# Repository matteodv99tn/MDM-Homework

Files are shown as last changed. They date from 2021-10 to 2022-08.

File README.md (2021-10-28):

# MDM-Homework
## LaTeX crash course

Le cose che vi spiego qua le scrivo abbastanza velocemente, la cosa più comoda è comunque provare e sperimentare, e in caso vedere anche la parte di documento già scritta.

Il testo si scrive normalmente nell'editor, ma per scrivere in modalità matematica nel testo bisogna mettere le funzioni matematiche nel simbolo del dollaro del tipo `$ f_l(x) = 10 $`; in modalità matematica con `_` si può indicare il pedice, con `^` l'apice.
Per andare a capo riga all'interno di uno stesso paragrafo non bisogna andare a capo riga nel domumento .tex ma basta mettere due barrette `\\` così. Per creare invece un nuovo paragrafo (ossia andare a capo riga e aggiungere un rientro alla prima riga) è necessario lasciare nell'editor di testo almeno una riga vuota.

Per scrivere le equazioni centrate in una nuva riga è possibile sfruttare due metodi: se l'equazione non deve essere numerata allora bisogna creare un nuovo ambiente 

`\begin{equation}`

      la mia equazione

 `\end{equation}`
 
 Se non si vuole avere il numero progressivo a destra basta inserire l'equazione in questo modo `\[ equazione \]`.

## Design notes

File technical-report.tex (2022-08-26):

\documentclass[11pt,a4paper]{article}
\usepackage[utf8]{inputenc}
\usepackage[T1]{fontenc}
\usepackage{amsmath}
\usepackage{amsfonts}
\usepackage{amssymb}
\usepackage{graphicx}
\usepackage{multicol}
\usepackage{etoolbox}
\usepackage[dvipsnames]{xcolor}
\usepackage[width=15.00cm, height=23.00cm]{geometry}
\usepackage[margin=1cm]{caption}
\usepackage[sorting=none]{biblatex} 
\usepackage{hyperref}
\usepackage{enumerate}
\usepackage{textcomp}
\usepackage{subcaption}
\usepackage{sidecap}
\usepackage{rotating}
\usepackage{subcaption}
\usepackage{pdfpages}

\addbibresource{bibliography.bib} 
\graphicspath{{Images/}}
\captionsetup{font = {it, small}, labelfont={color=NavyBlue, bf}}

%% Fonts
\usepackage[osf,sc]{mathpazo}
\usepackage[scaled=0.90]{helvet}
\usepackage[scaled=0.85]{beramono}

\begin{document}
	
	\pagenumbering{roman}
	\thispagestyle{empty}
	\begin{center}
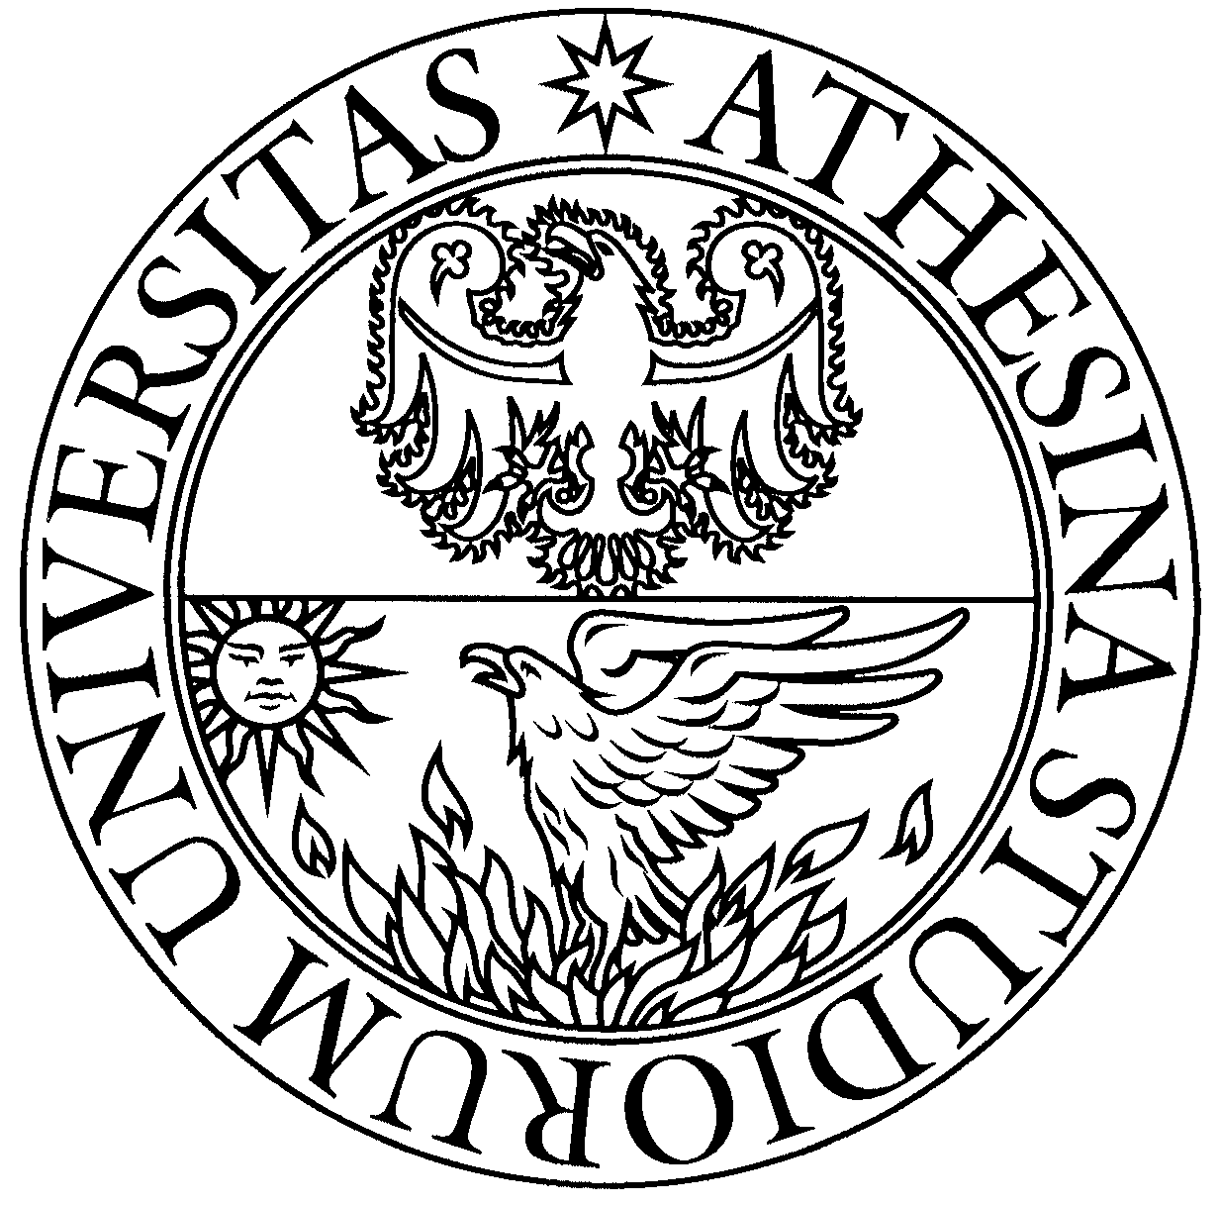
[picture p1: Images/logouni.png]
		
		\vspace{2cm}
		
		{\Large Group project for the course of \\ \vspace{3mm}
		\textbf{Mechanical Design for Mechatronics} \\ \vspace{1cm}
		Prof.: Rustighi Emiliano} \vspace{1cm}
	
		\rule{5cm}{0.5pt} \\ \vspace{1cm}
		{\Large Technical report} \\ \vspace{3mm}
		{\LARGE \textbf{Design of the Structure of an Automated Machine \\ for Agricultural Purposes}} \\ \vspace{1cm}
		
		\rule{5cm}{0.5pt} \vspace{1cm}
		
		\begin{multicols}{2}
			Bontempelli Elia \\
			Rizzardi Alessandro \\
			Dalle Vedove Matteo \\
			Zambotti Beatrice
		\end{multicols}
		\vspace{1cm}
		
		\today
		
	\end{center}
	
	\newpage
	\tableofcontents
	
	\newpage
	
	\pagenumbering{arabic}
	\setcounter{page}{1}
	
	% Importare qua le varie sezioni
	\input{Parts/designspecification}
	\input{Parts/preliminarydesign}
	\input{Parts/design}
	\input{Parts/developement}
	\input{Parts/conclusions}

	\appendix	
	\counterwithin{figure}{section}
	\counterwithin{table}{section}

	% Inserire da qua le appendici
	\clearpage
	\section{Appendix}
	\counterwithin{table}{subsection}
	\input{Appendix/material.tex}
	\input{Appendix/BOM.tex}
	\input{Appendix/drawings.tex}
	
	\clearpage
	\section{Bibliography and references}
	In order of first appearance:
	\printbibliography[heading=none]
	
	\newpage
	%\input{LatexCrashCourse}
	
\end{document}

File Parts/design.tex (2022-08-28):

\section{Preliminary design}
	Based on the selected concept the simplest body diagram has been created in order to start the dimensioning of the main elements of the structure. Considering the possible practical implementation of the system, the symbolic representation of the moving frame has been made (figure \ref{fig:freebodydiagramframe}).
	
	\begin{figure}[bht]
		\centering 
		\caption{schematic representation of the moving frame supporting the arm; blue arrows are describes the rotational degree of freedom left by the joints.}
		\label{fig:freebodydiagramframe}
	\end{figure}
	
	The design involves a main elevated track (body 2) supported by two vertical supporting beams (bodies 1 and 3); the connection between body 1 and 2 is constituted by a full joint in point $B$ constraining all 6 degrees of freedom while the connection of the track with the other support is done by a hinge that leaves free the rotation over the global $x$ axis. The two vertical supports can slide on two parallel tracks and the associated prismatic joints constraints respectively 5 and 4 degrees of freedom in $A$ and $D$, leaving the system free to slide along the $x$ global axis; the choice of leaving also $D$ in as free to rotate aims at reducing redundant constraints, reducing hyperstatic variables with a design that accommodates misalignments in the position of the two parallel tracks placed at ground.

	\begin{figure}[p]
		\begin{subfigure}{\linewidth}			
			\centering  \caption{}
		\end{subfigure}
		\begin{subfigure}{\linewidth}			
			\centering  \caption{}
		\end{subfigure}
		\caption{free body diagram (a) and reference frames (b) used for the description of the internal loads of the beam. In (a) the structure has been disassembled at the pivot point $C$ in order to describe the reaction forces transmitted.}
		\label{fig:fbd-frames}
	\end{figure}
	As simplification on both the geometry and the load we consider:
	\begin{itemize}
		\item on the elevated track the loads transferred by the working appendix are modelled as a pure vertical force $F$ (mainly related to the approximate weight of the turret that contains all equipment) and a torque $T$ that model's the one due to the plower; the eccentricities of both forces are in this case neglected and the application of application of both actions is placed at a distance $\zeta$ referred to the local coordinate $z$ of the elevated track, figure \ref{fig:fbd-frames}\textit{\textit{(b)}};
		
		\item the vertical supports are equally dimensioned and present a characteristic height $H = 700mm$; the elevated track connecting them has length $L = 3000mm$ as dictated by the customer requirements;
		
		\item figure \ref{fig:fbd-frames}\textit{(a)} shows the free body diagram of the structure and thus the set of external actions and reactions applied; figure \ref{fig:fbd-frames}\textit{(b)} reports instead the reference frames with respective origin with respect to which internal loads are calculated.
		
		The full joint in $B$ has not been described (as the connection preserves the continuity of the actions transmitted by the body), however the final design will imply the connection of two separate beams by means of a gusset.	
		
	\end{itemize}
	
	After having written the Newton-Euler equations of the two bodies making the whole structure, we observe that only 11 out of 14 reactions forces are independent; chosen the hyperstatic variables $X_1 = M_{Az},X_2 = M_{Dy}, X_3 = M_{Ax}$ to reduce the problem to an isostatic one, the parametric definitions of the reaction forces is
	\[ R_{Az} = \frac{F (L-\zeta) - X_3}{L} \qquad R_{Cz} = R_{Dz} =\frac{F\zeta + X_3}{L} \] \[ M_{Ay} = M_{Cy} = X_2 \qquad M_{Cz} = M_{Dz} = T-X_1 \]
	Non mentioned actions are identically zero. To solve the hyper-static problem the Castigliano's theorem has been used, computing the elastic energy $U_e$ of the structure neglecting shear loads:
	\[ U_e = \sum_{i=1}^3 \int_0 ^{l_i}  \left( \frac{N_i^2}{2EA_i} + \frac{M_{x,i}^2}{2 EI_{xx,i}} + \frac{M_{y,i}^2}{2 E I_{yy,i}} + \frac{M_{z,i}^2}{2G J_{t,i}}  \right)\, dz \]
	Assuming the generalized displacement related to the hyper-static variables is zero, solving the equations $\partial U_e / \partial X_i = 0$, the solution that we achieve is still depending on the geometrical parameters of the sections that are still unknown. To simplify the calculations we assumed $A_1 = 0$, giving the result
	\[ X_1 = T \qquad X_2 = 0 \qquad X_3 = F \frac{L-2\zeta}{2} \]

	In this preliminary design phase in order to over-estimate the loads the the frame should bear a force $F = 200 N$ is considered (modelling the weight of about $20kg$, related to all the carried equipment on the moving arm including batteries and filled water tank) and the nominal value of the torque $T = 0.8 N\cdot m$ as in the requirements specification.
	
	\paragraph{Choice of the standard beams} With the preliminary design model described, different solutions can be found looking from various vendors present in the marker. In particular for the project main reference has been made to the Parker IPS catalogue \cite{parker-ds} due to the high availability of accessories components, however similar product can be found by other vendors (as group we also evaluated 8020 \cite{8020-ds} and Tslots by Bonnel Aluminum \cite{tslot-ds}).
	
	Data-sheets presents information about the section area $A$ and second moments of area $I_{xx},I_{yy}$ respect the primary axes, however no information is given for the torsional rigidity $J_t$ and so the related component is in the calculation neglected. 
	
	\input{Table/beamchoice.tex}
	
	After an iterative process, table \ref{tab:beamchoice} shows the sections drawing and associated geometric properties of the chosen components for both elevated track and supporting beams. This choice determines a safety factor $\phi = 3.8$ for the whole structure that's a safe value for us; it is true that we neglected both shear and torque loads, and in practical applications other external and unexpected actions might act on the frame, however it is also true that the geometric simplification $A_1 = 0$ in the solution of the hyperstatic problem heavily reduced the ability of the system to bear load (as we will see in the final static verification).
	
	As a side note, our design was forced to use the $40mm$ T-slot series (even if a $30mm$ profile would have let us achieve similar results with lower weights and costs) as it's the only one that disposes off-the-shelf linear roller system that can be easily mounted and used (choosing other profile series would have ended in custom solution that's undesired by the product design specifications).

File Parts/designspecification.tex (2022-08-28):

\section{Product design specification}
	The goal of our project is to create our implementation of the \textit{CyberOrto} \cite{cyberorto} made by \textit{Mindshub}, a non-lucrative association based in Ala (Trentino). The goal of this robot is to automatically handle an amateur vegetable garden by performing this 3 principle actions:
	\begin{enumerate}[i)]
		\item planting the seeds  of the desired plant in a location decided by the user using a web interface;
		\item constantly provide water to the vegetable;
		\item extirpate undesired plants.
	\end{enumerate}

	By talking with the association that worked (and is still improving) on the product we acknowledged the following requirements (mainly related to the functionality of the product) that the machine has to satisfy:
	\begin{enumerate}[i)]
		\item the arm appendix must suits an interface that allows to have an interchangeable set of tools (like the one used to plow the terrain or plant the seeds);
		
		\item the arm appendix should accommodate a small pipe in order to irrigate the vegetables; in particular this has to be connected to an external reservoir (with arbitrary dimension) or by using an internal reservoir on the moving structure of at least $4l$ (that can periodically be refilled by means of a resting station) if it's not possible to directly attach the arm to the main reservoir;
		
		\item the minimum accepted working area of the robot is a rectangle of dimension $4m\times 3m$; the robot should be design keeping in mind the possibility to increase the working area by expanding it over one edge (for example having the possibility to work on a $8m\times 3m$ terrain);
		
		\item the structure can house the electronic control unit of the robot that's remotely connected to the server using wireless connection and by doing so should accommodate a battery the allows the robot to work for at least $4h$. The power consumption of the structure should be minimized if possible (at the actual state the prototype consumes $40W$ and has a battery of $240 Wh$ weighting $6.3kg$);
		
		\item regarding the accuracy of the movement of the system the allowed backlash on the working point should always be less then $1cm$ with the control technique implemented and the goal is to have maximum $5mm$ of deviation from the nominal value;
		
		\item the structure should be mainly composed of standard components and should be as cheap as possible in order to make it affordable for everyone.
	\end{enumerate}

	\paragraph{Loads and operating conditions} The structure should be able to perform all it's operation while being safe and fully functional. For the design and the verification of the structure the loads related to wind can be neglected due to the presence of an anemometer that's mounted on the robot that's ensuring that the robot works only on a sufficiently safe environment.
	
	The heavier operation performed by the robot is the extirpation that's done by plowing the soil with a rotating disk attached to a motor that uses three nails to move the terrain in the nearby of the target zone. In the current state the mounted motor that performs this operation exerts a torque $T_\textrm{plower} = 0.8 N\cdot m$, value that will be used for the dimensioning and verification phases.

	\subsection{Requirements \& specifications}
		With this premise being said, it's possible to express the main requirements, associated to the aim dictated by our customer and our design rules, and the specifications of the designed machine. All this information, collected in table \ref{tab:requirementsspecifications}, must be considered in each step of the design phase in order to develop the mechanical solution.
		
		\input{Tables/requirements-specifications.tex}
		
		While developing the project other factors should be kept in mind such:
		\begin{itemize}
			\item the possibility to pack all the necessary components in a \textit{small} transportation box (the box shouldn't present and edge greater than $2m$, maximum sum of all the edges less then $3m$) in order to avoid shipping issues;
			
			\item the kit should be feasible to all private enthusiast that enjoy \textit{do-it-yourself} projects and this has to kept in mind; the final assembly should be made possible by common mounting tools (such screwdrivers, Allen keys...) that can be easily purchased and used by the customer; for the same reason welding finishes are not recommended.
		\end{itemize}
	
	\subsection{Goal of our project}
		Designing the whole machine is out of our scopes as it is very complex and requires knowledge that we still miss, so we decided to focus our work in the design of the main structure of the robot putting effort in the structural verification as the goal of the course.

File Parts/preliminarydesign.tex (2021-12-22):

\section{Concept generation}
	With all the premise that lead the development of the project, the first thing that has to be done is generate the concept that can later be compared to choose the best design solution that can become a concrete realization of the ideas.
	
	\paragraph{Kinematic configurations} The first key operation that the robot has to perform is reaching a desired point on the working space and so, in planar kinematics, the machine should present two degrees of freedom that allow to reach all the possible positions; this can be done considering 3 main joint configuration that allows to perform such operations:
	\begin{itemize}
		\item double prismatic joints (figure \ref{fig:kinematiccoupling}.a) where two perpendicular linear guides can be used to move on the plane;
		\item prismatic and revolute joint (figure \ref{fig:kinematiccoupling}.b) where the arm that's free to rotate it's mounted on top of a linear guide. This kind of kinematic chain is currently used by the MindsHub concept;
		\item double revolute joints (figure \ref{fig:kinematiccoupling}.c), typical configuration of a robot arm, that constraint the framing point to be fixed.
	\end{itemize}
	
	\begin{figure}[bht]
	\centering
		\begin{subfigure}{0.32\linewidth}
			\centering 
			\caption{}
		\end{subfigure}
		\begin{subfigure}{0.32\linewidth}
			\centering 
			\caption{}
		\end{subfigure}
		\begin{subfigure}{0.32\linewidth}
			\centering 
			\caption{}
		\end{subfigure}
		\caption{main kinematics coupling that allows to univocally determine the position of a point $A$ in a plane: (a) double prismatic joints, (b) prismatic and revolute joint, (c) double revolute joints.}
		\label{fig:kinematiccoupling}
	\end{figure}
	
	By a first analysis the third configuration (double revolute joint) isn't feasible for the project due to the fact that the system presents a fixed pivot point respect to the frame and to work more area it's mandatory to increase the length of the edges (and this is an issue for the \textit{extendibility} of the machine).
	
	\paragraph{Concept \#1} The first concept (figure \ref{fig:prot:1}) is realised with a double prismatic joint. In particular point $A$ and $A'$ lies on parallel tracks placed on the ground that can be extended in order to increase the cultivated area. The working arm can move along an elevated beam connecting the track (point $B$) and can move vertically to cultivate point $P$.
	
	\begin{figure}[bht]
		\centering 
		\caption{concept \#1 realised with double prismatic joint.}
		\label{fig:prot:1}
	\end{figure}
	
	This structure present a frame for the arm that's stable while operating due to it's arch structure; possible problem to this implementation is that long elevated beam (subjected to the loads of the arms and it's mass) can deflect and fail statically. Also, if possible, rotoidal coupling should be used (and for this we can refer to concept \#2).
	
	\paragraph{Concept \#2}	The second concept (figure \ref{fig:prot:2}) is similar to the first one but one prismatic joint is replaced with a revolute connection put in the middle of the elevated beam. The length of the edge $BP$ from a top view must be equal to half the length of the supporting bar in order to reach all points in the rectangular space.

	\begin{figure}[bht]
		\centering 
		\caption{concept \#2 realised with a combination of both prismatic and revolute joint.}
		\label{fig:prot:2}
	\end{figure}
	
	This structure also presents the pro of concept \#1 of having a stable frame structure for the operating arm due to it's arch conformation and, as addition, uses a revolute joint to control the second degree of freedom of the arm. However this implementation increases the mechanical load on the elevated beam (increasing the torsion due to the higher arm of the actions on the tool tip respect to the elevated bar).
	
	\paragraph{Concept \#3}	The third concept (figure \ref{fig:prot:3}) is similar to \#2 but instead of using two parallel tracks, the prismatic joint uses only one of them.

	\begin{SCfigure}[1.5][bht]
		\centering 
		\caption{concept \#3  realised with a combination of both prismatic and revolute joint.}
		\label{fig:prot:3}
	\end{SCfigure}

	This implementation avoid the problem of high deflection of concepts \#1 and \#2 by removing the long elevated framing beam, but also increases the reactional momentum that the prismatic joint $A$ should bear in order to maintain stable the system.

\subsection{Decision matrix}
	With a brief overview of the 3 main concept generated, the unbiased choice can be performed by constructing and evaluating the decision matrix (table \ref{tab:decitionmatrix}). The main objective evaluated are:
	
	\input{Table/decisionmatrix.tex}
	
	\begin{itemize}
		\item costs: based on the estimated material cost considering quantity and types of parts that can be used for the implementation;
		\item reliability: expected mechanical  resistance of the structure subjected to nominal loads as well as unexpected external loads (such environment of customer that interact with the structure);
		
		\item lifetime: expected lifetime of the product based on fatigue considerations;
		
		\item adaptability: criteria that evaluates how easy is to modify geometrical parameters to meet specific custom requirement of the final customer based on asperity and tolerances of the terrain to cultivate;
		
		\item team experience: based on the overall design feasibility made by the team.
	\end{itemize}

	With the decision matrix completed the chosen concept is the first on which the motion is performed only by prismatic joints.

\input{Parts/materialselection}

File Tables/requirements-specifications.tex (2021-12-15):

\begin{table}[pbt]
	\rule{\linewidth}{2pt}
	\caption{full list of requirements and specifications for the CyberOrto project.}
	\label{tab:requirementsspecifications}
	\rule{\linewidth}{1pt} \vspace{0mm}	
	
	\centering
	\begin{tabular}{p{0.2cm} p{8cm} p{5cm} }
		\multicolumn{2}{l}{ \textbf{1) Geometry:} } \\
		& 1.1) dimension of the terrain to cultive & at least $4m\times 3m$, extendible if possible \\
		& 1.2) vertical clearance from the ground of the robot while moving & $\geq 50cm$ \\
		
		\multicolumn{2}{l}{ \textbf{2) Kinematic:} } \\
		& 2.1) time travel between further points in the field & $ \leq 10s$ \\	
		& 2.2) accuracy of the working appendix respect to nominal value & max $\pm 1cm$, target $\pm 5mm$ \\		
		
		\multicolumn{2}{l}{ \textbf{3) Energy:} } \\
		& 3.1) low energy consumption & max $40W$, target $20W$ \\
		& 3.2) in-device battery with docking station & battery $\geq 240 Wh$ or $4+$ hour of work\\
				
		\multicolumn{2}{l}{ \textbf{4) Functionalities:} } \\
		& 4.1a) provide direct water access to irrigate the soil \\
		& 4.1b) or provide a reservoir that can be automatically refilled on a docking station & $\geq 4l$ \\
		& 4.2) standard mount on the appendix arm that can fit multiple working tools \\
		& 4.3) plowing the terrain & $T_\textrm{plower,max} = 0.8 N\cdot m $\\
		& 4.4) provide a pneumatic circuit used for the appendix that plants seeds \\
		
		\multicolumn{2}{l}{ \textbf{5) Materials:} } \\
		& 5.1) components standardization & very high \\
		& 5.2) materials should be weather proof (oxidation free) \\
		
		\multicolumn{2}{l}{ \textbf{6) Terms of use:} } \\
		& 6.1) easy to assemble & max 2 persons required \\
		& 6.2) fatigue resistance & infinite life-cycles if possible, min $10^6$ \\
		& 6.3) insensible to environmental conditions (weather and dirt)\\

		\multicolumn{2}{l}{ \textbf{7) Loading conditions:} } \\
		&  7.1) wind and environmental actions can be neglected with robot in action\\
		
		\multicolumn{2}{l}{ \textbf{8) Costs:} } & $\leq \textrm{\texteuro}2\,000$ \\
	\end{tabular}
	
	\vspace{3mm}
	
	\rule{\linewidth}{2pt}

\end{table}

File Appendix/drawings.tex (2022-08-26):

\clearpage
\section{Technical drawings}
\subsection{Gear and rack design} \label{draw:gearrack}
In the following page the detailed representation of the custom created rack and gear design is reported.

\includepdf[fitpaper=true]{Drawings/rack.pdf}
\includepdf[fitpaper=true]{Drawings/gear.pdf}

\subsection{Final CAD}

\includepdf[fitpaper=true]{Drawings/Overview.pdf}

\subsection{Connection assembly details}
In the following pages it's possible to find instructions on how to assembly the rack on top of the T-slot profiles and how to assemble the main junctions of the frame, namely connections $A$, $B$, $C$ and $D$.

\includepdf[fitpaper=true]{Drawings/Mounting.pdf}
\includepdf[fitpaper=true]{Drawings/Connessione-A.pdf}
\includepdf[fitpaper=true]{Drawings/Connessione-B.pdf}
\includepdf[fitpaper=true]{Drawings/Connessione-C.pdf}
\includepdf[fitpaper=true]{Drawings/Connessione-D.pdf}

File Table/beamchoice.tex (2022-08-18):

\begin{table}[bt]
	\rule{\linewidth}{2pt}
	\caption{selected beams section chosen from the Parker IPS catalogue \cite{parker-ds} and related main properties (area, moments of inertia and weight per unit length).}
	\label{tab:beamchoice}
	\rule{\linewidth}{1pt} \vspace{0mm}	
	
	\begin{center}
		\begin{tabular}{p{3cm} | c c c c  |  l }
			& Area & \multicolumn{2}{c}{Moments of inertia} & Weight \\
			Usage & $A [cm^2]$ & $I_{xx} [cm^4]$ & $I_{yy} [cm^4]$ & $\rho [kg/m]$ & Product code \\ \hline
			track & 6.65 & 9.46 & 9.46 & 1.72 & \texttt{10-040} \\
			supports & 5.20 & 8.27 & 8.27 & 1.41 & \texttt{10-540} \\
		\end{tabular}
	\end{center}
	
	\vspace{3mm}
	\rule{\linewidth}{1pt}
	{\scriptsize
		\begin{multicols}{2}
		\begin{center}
				\\		
			
		\end{center}
		\end{multicols}
		Sections for the track beam (on the left) and the supports (right).
	}	
	
	\rule{\linewidth}{2pt}
	
\end{table}

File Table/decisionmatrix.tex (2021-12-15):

\begin{sidewaystable}[p]
	\rule{\linewidth}{2pt}
	\caption{decision matrix.}
	\label{tab:decitionmatrix}
	\rule{\linewidth}{1pt} \vspace{0mm}	
	
	\begin{center}
		\begin{tabular}{p{3cm} c c | c c c | c c c | c c c}
			\multicolumn{3}{c}{} & \multicolumn{3}{c}{Concept \#1} & \multicolumn{3}{c}{Concept \#2} & \multicolumn{3}{c}{Concept \#3} \\
			Objective &  Weight & Parameter &
			Mag & Score & Value &
			Mag & Score & Value &
			Mag & Score & Value \\ \hline
			Material costs & 0.2 & relative \texteuro &
			medium & 7 & 1.4 &
			high & 5 & 1 & 
			low & 9 & 1.8 \\
			
			Reliability & 0.3 & experience &
			good & 8 & 2.4 &
			okay & 6 & 1.8 & 
			poor-fair & 3 & 0.9 \\
			
			Lifetime & 0.15 & experience &
			great & 10 & 1.5 &
			good & 8 & 1.2 & 
			fair & 4 & 0.6 \\
			
			Adaptability & 0.2 & experience &
			good & 8 & 1.6 &
			okay-good & 7 & 1.4 & 
			fair & 4 & 0.8 \\
			
			Team experience & 0.15 & experience &
			good & 8 & 1.2 &
			great & 10 & 1.5 & 
			fair & 4 & 0.6 \\			
			
			\hline
			\multicolumn{3}{r|}{Overall score:} &&& \textbf{8.1} &&& 6.9 &&& 4.7
		\end{tabular}
	\end{center}
	
	\vspace{3mm}
	\rule{\linewidth}{1pt}
	{
		\scriptsize
		Qualitative score assignments:  poor = 2, fair = 4, okay = 6, good = 8, great = 10.
	}	
	
	\rule{\linewidth}{2pt}
	
\end{sidewaystable}

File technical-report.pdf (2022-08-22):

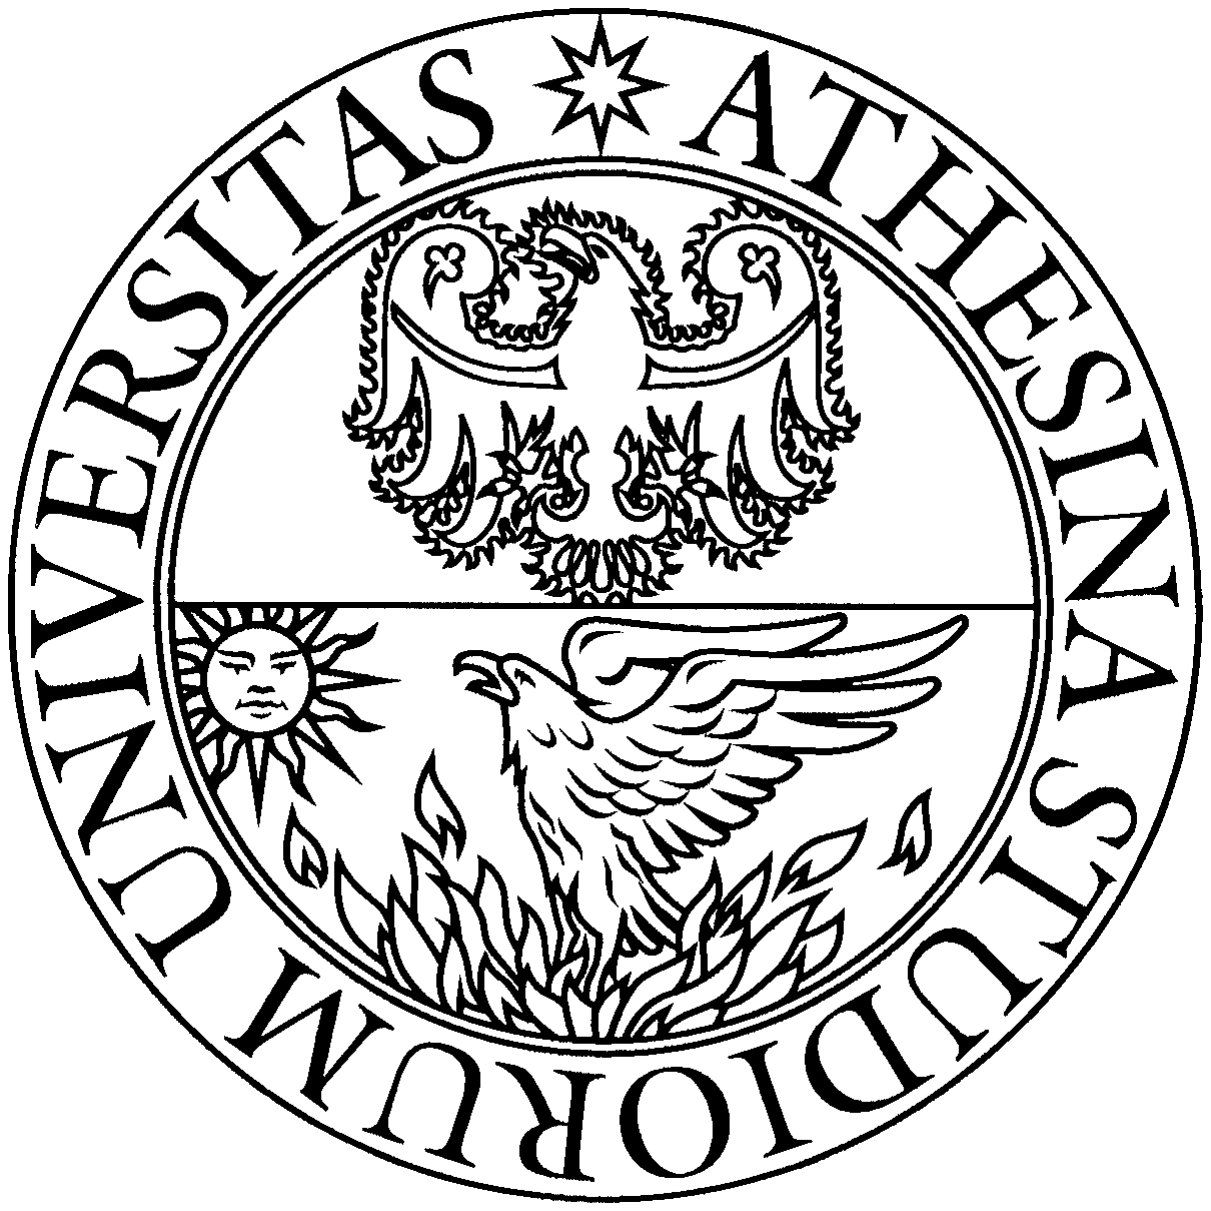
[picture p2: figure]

## Group project for the course of

### Mechanical Design for Mechatronics

## Prof.: Rustighi Emiliano

## Technical report

## Design of the Structure of an Automated Machine for Agricultural Purposes

Bontempelli Elia
Rizzardi Alessandro

Dalle Vedove Matteo
Zambotti Beatrice

August 22, 2022

### Contents

1 Product design specification | 1
2 Concept generation | 2
3 Preliminary design | 8
4 Design process and verifications | 11
A Appendix | 22
B Bibliography and references | 26

ii

### 1 Product design specification

The goal of our project is to create our implementation of the CyberOrto [1] made by Mindshub, a non-lucrative association based in Ala (Trentino). The goal of this robot is to automatically handle an amateur vegetable garden by performing this 3 principle actions:

i) planting the seeds of the desired plant in a location decided by the user using a web interface;

ii) constantly provide water to the vegetable;

iii) extirpate undesired plants.

By talking with the association that worked (and is still improving) on the product we acknowledged the following requirements (mainly related to the functionality of the product) that the machine has to satisfy:

i) the arm appendix must suits an interface that allows to have an interchangeable set of tools (like the one use to plow the terrain);

ii) the arm appendix should accommodate a small pipe in order to irrigate the vegetables; in particular this has to be connected to an external reservoir (with no dimension specified if it’s position is fixed) or by using an internal reservoir on the moving structure of at least 4l (that can periodically be refilled) if it’s not possible to directly attach the arm to the main reservoir;

iii) the minimum accepted working area of the robot is a rectangle of dimension 4m × 3m; the robot should be design keeping in mind the possibility to increase the working area by expanding it over one edge (for example having the possibility to work on a 8m × 3m terrain);

iv) the structure can house the electronic control unit of the robot that’s remotely connected to the server using wireless connection and by doing so should accommodate a battery the allows the robot to work for at least 4h. The power consumption of the structure should be minimized if possible (at the actual state the prototype consumes 40W and has a battery of 240Wh weighting 6.3kg);

v) regarding the accuracy of the movement of the system the allowed backlash on the working point should always be less then 1cm with the control technique implemented and the goal is to have maximum 5mm of deviation from the nominal value;

vi) the structure should be mainly composed of standard components and should be as cheap as possible in order to make it affordable for everyone.

Loads and operating conditions The structure should be able to perform all it’s operation while being safe and fully functional. For the design and the verification of the structure the loads related to wind can be neglected due to the presence of an anemometer that’s mounted on the robot that’s ensuring that the robot works only on a sufficiently safe environment.

1

The heavier operation performed by the robot is the extirpation that’s done by plowing the soil with a rotating element AGGIUNGERE UNA BREVE DESCRIZIONE. Considering the actual mounted motor to perform this operation the torque that has to be transmitted to the plower is of Tplower = 0.8N · m.

### 1.1 Requirements & specifications

With this promise being said, it’s possible to express the main requirements, associated to the aim dictated by our customer and our design rules, and the specifications of the designed machine. All this information, collected in table 1, has to be considered in each step of the design phase in order to develop the mechanical solution.
While developing the project other factors should be kept in mind:
- the possibility to pack all the necessary components in a small transportation box (the box shouldn’t present and edge greater than 2m, maximum sum of all the edges less then 3m) in order to avoid shipping issues;
- the kit should be feasible to all private enthusiast that enjoy do-it-yourself projects and this has to kept in mind; the final assembly should be made possible by common mounting tools (such screwdrivers, Allen keys...) that can be easily purchased and used by the customer; for the same reason welding finishes are not recommended.

### 1.2 Goal of our project

Designing the whole machine is out of our scopes as it is very complex and requires knowledge that we still miss, so we decided to focus our work in the design of the main structure of the robot putting effort in the structural verification as the goal of the course.

### 2 Concept generation

With all the premise that lead the development of the project, the first thing that has to be done is generate the concept that can later be compared to choose the best design solution that can become a concrete realization of the ideas.

Kinematic configurations The first key operation that the robot has to perform is reaching a desired point on the working space and so, in planar kinematics, the machine should present two degrees of freedom that allow to reach all the possible positions; this can be done considering 3 main joint configuration that allows to perform such operations:

- double prismatic joints (figure 1.a) where two perpendicular linear guides can be used to move on the plane;
- prismatic and revolute joint (figure 1.b) where the arm that’s free to rotate it’s mounted on top of a linear guide. This kind of kinematic chain is currently used by the MindsHub concept;

2

Table 1: full list of requirements and specifications for the CyberOrto project.

1) Geometry:
1.1) dimension of the terrain to cultive | at least 4m × 3m, extendible
| if possible
1.2) vertical clearance from the ground of the
robot while moving | ≥ 50cm
2) Kinematic:
2.1) time travel between further points in the
field | ≤ 10s
2.2) accuracy of the working appendix respect
to nominal value | max ±1cm, target ±5mm
3) Energy:
3.1) low energy consumption | max 40W, target 20W
3.2) in-device battery with docking station | battery ≥ 240Wh or 4+ hour
| of work
4) Functionalities:
4.1a) provide direct water access to irrigate the
soil
4.1b) or provide a reservoir that can be auto- matically refilled on a docking station | ≥ 4l
4.2) standard mount on the appendix arm that
can fit multiple working tools
4.3) plowing the terrain | Tplower,max = 0.8N · m
4.4) provide a pneumatic circuit used for the
appendix that plants seeds
5) Materials:
5.1) components standardization | very high
5.2) materials should be weather proof (oxidation free)
6) Terms of use:
6.1) easy to assemble | max 2 persons required
6.2) fatigue resistance | infinite life-cycles if possible,
| min 10⁶
6.3) insensible to environmental conditions
(weather and dirt)
7) Loading conditions:
7.1) wind and environmental actions can be neglected with robot in action
8) Costs: | ≤ €2 000

3

- double revolute joints (figure 1.c), typical configuration of a robot arm, that constraint the framing point to be fixed.

(a)

A

(b)

A

(c)

Figure 1: main kinematics coupling that allows to univocally determine the position of a point A in a plane: (a) double prismatic joints, (b) prismatic and revolute joint, (c) double revolute joints.

By a first analysis the third configuration (double revolute joint) isn’t feasible for the project due to the fact that the system presents a fixed pivot point respect to the frame and to work more area it’s mandatory to increase the length of the edges (and this is an issue for the extendibility of the machine).

Concept #1 The first concept (figure 2) is realised with a double prismatic joint. In particular point A and A

′
lies on parallel tracks placed on the ground that can be extended in order to increase the cultivated area. The working arm can move along an elevated beam connecting the track (point B) and can move vertically to cultivate point P.

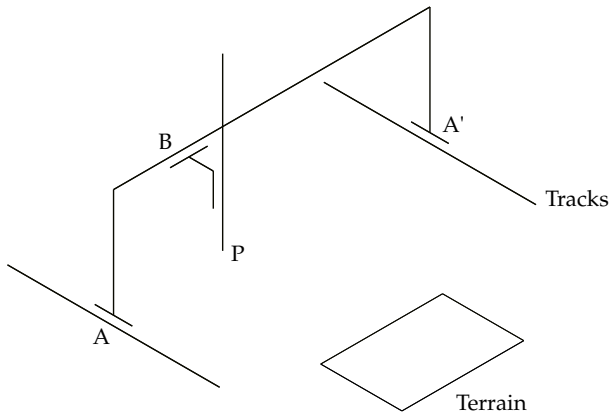
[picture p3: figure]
Terrain; Tracks

Figure 2: concept #1 realised with double prismatic joint.

This structure present a frame for the arm that’s stable while operating due to it’s arch structure; possible problem to this implementation is that long elevated beam (subjected to the loads of the arms and it’s mass) can deflect and fail statically. Also, if possible, rotoidal coupling should be used (and for this we can refer to concept #2).

4

Concept #2 The second concept (figure 3) is similar to the first one but one prismatic joint is replaced with a revolute connection put in the middle of the elevated beam. The length of the edge BP from a top view must be equal to half the length of the supporting bar in order to reach all points in the rectangular space.

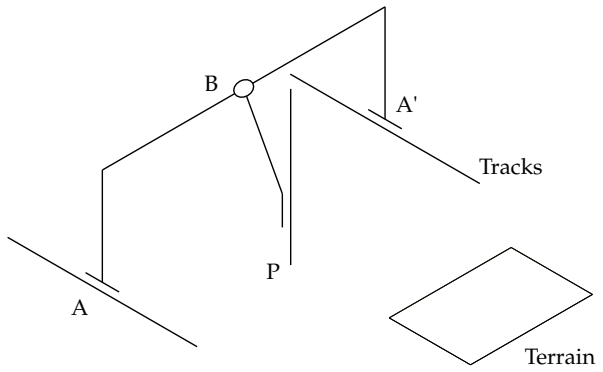
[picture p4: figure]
Terrain; Tracks

Figure 3: concept #2 realised with a combination of both prismatic and revolute joint.

This structure also presents the pro of concept #1 of having a stable frame structure for the operating arm due to it’s arch conformation and, as addition, uses a revolute joint to control the second degree of freedom of the arm. However this implementation increases the mechanical load on the elevated beam (increasing the torsion due to the higher arm of the actions on the tool tip respect to the elevated bar).

Concept #3 The third concept (figure 4) is similar to #2 but instead of using two parallel tracks, the prismatic joint uses only one of them.

Terrain

A

B

P
Figure 4: concept #3 realised with a combination of both prismatic and revolute joint.

This implementation avoid the problem of high deflection of concepts #1 and #2 by removing the long elevated framing beam, but also increases the reactional momentum that the prismatic joint A should bear in order to maintain stable the system.

### 2.1 Decision matrix

With a brief overview of the 3 main concept generated, the unbiased choice can be performed by constructing and evaluating the decision matrix (table 2). The main objective evaluated are:

- costs: based on the estimated material cost considering quantity and types of parts that can be used for the implementation;
- reliability: expected mechanical resistance of the structure subjected to nominal loads as well as unexpected external loads (such environment of customer that interact with the structure);

5

Table 2: decision matrix.

Concept #1 Concept #2 Concept #3

Objective Weight Parameter Mag Score Value Mag Score Value Mag Score Value

### Material costs 0.2 relative € medium 7 1.4 high 5 1 low 9 1.8

Reliability 0.3 experience good 8 2.4 okay 6 1.8 poor-fair 3 0.9

Lifetime 0.15 experience great 10 1.5 good 8 1.2 fair 4 0.6

Adaptability 0.2 experience good 8 1.6 okay-good 7 1.4 fair 4 0.8

Team experience 0.15 experience good 8 1.2 great 10 1.5 fair 4 0.6
Overall score: 8.1 6.9 4.7

Qualitative score assignments: poor = 2, fair = 4, okay = 6, good = 8, great = 10.

6

- lifetime: expected lifetime of the product based on fatigue considerations;
- adaptability: criteria that evaluates how easy is to modify geometrical parameters to meet specific custom requirement of the final customer based on asperity and tolerances of the terrain to cultivate;
- team experience: based on the overall design feasibility made by the team.

With the decision matrix completed the chosen concept is the first on which the motion is performed only by prismatic joints.

### 2.2 Material selection

The main structural components are beams that, for client requirements, should be standard and so for this reason T slot extruded aluminium profiles (figure 5) are chosen after the following considerations:

- better volume-to-price ratio and lower density (respect to inox steels), so reducing costs associated to the spare parts and shipping;
- availability in the market: there are a lot of vendors that provide profiles with various geometrical dimensions, different aluminium alloy and surface finishes. This spare parts can be easily accessed by every private costumer;
- for T slot extruded profiles lots of auxiliary components (such supporting brackets, fasteners, hinges...) are provided from the same profiles manufacturers, reducing the need of custom made part and so decreasing the overall costs.

This elements can be also purchased with an anodized finish that allows to improve the corrosion resistance, increasing so the expected life time of the product in uncontrolled outdoor environment.

Figure 5: technical drawing of a T-slot profile’s cross-section. The particular sketch represent the model TS40-40LM by Tslots [2].

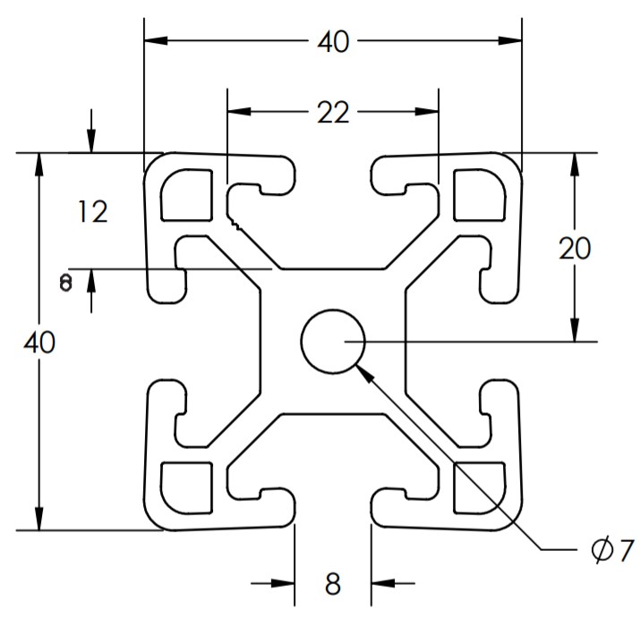
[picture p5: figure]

Mechanical properties For the design part the following mechanical properties are considered: ultimate tensile strength σuts = 260MPa, yielding strength σys = 240MPa, Young’s module E = 70GPa, Poisson’s ratio ν = 0.32; this values are chosen according to table A.1.1 (page 22) as they represent a lower bound (implying higher safety in calculations) for the aluminium material used for the T-Slot sections.

7

### 3 Preliminary design

Based on the selected concept the simplest body diagram has been created in order to start the dimensioning of the main elements of the structure. Considering the possible practical implementation of the system, the symbolic representation of the moving frame

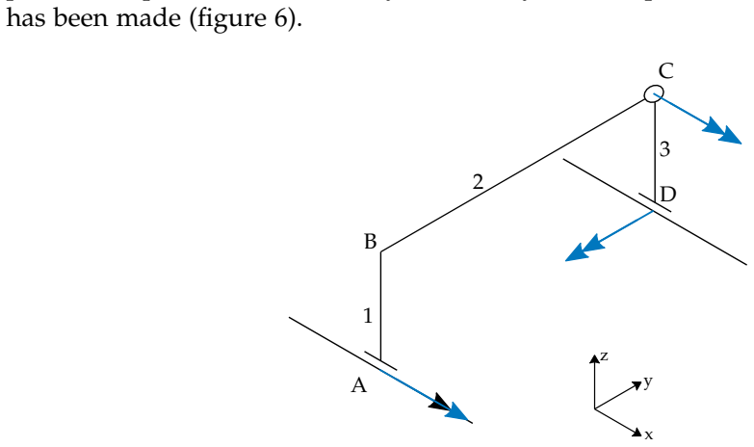
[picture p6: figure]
has been made (figure 6).

Figure 6: schematic representation of the moving frame supporting the arm; blue arrows are describes the rotational degree of freedom left by the joints. FIGURA DA MODIFICARE

The design involves a main elevated track (body 2) supported by two vertical supporting beams (bodies 1 and 3); the connection between body 1 and 2 is constituted by a full joint in point B constraining all 6 degrees of freedom while the connection of the track with the other support is done by a hinge that leaves free the rotation over the global x axis. The two vertical supports can slide on two parallel tracks and the associated prismatic joints constraints respectively 5 and 4 degrees of freedom in A and D, leaving the system free to slide along the x global axis; the choice of leaving also D in as free to rotate aims at reducing redundant constraints, with the aim of reducing hyperstatic variables with a design that accommodates misalignments in the position of the two parallel tracks placed at ground.
As simplification on both the geometry and the load we consider:
- on the elevated track the loads transferred by the working appendix are modelled as a pure vertical force F (mainly related to the approximate weight of the turret that contains all equipment) and a torque T that model’s the one due to the plower; the eccentricities of both forces are in this case neglected and the application of application of both actions is placed at a distance ζ referred to the local coordinate z of the elevated track, figure 7(b);
- the vertical supports are equally dimensioned and present a characteristic height H = 700mm; the elevated track connecting them has length L = 3000mm as dictated by the customer requirements;
- figure 7(a) shows the free body diagram of the structure and thus the set of external actions and reactions applied; figure 7(b) reports instead the reference frames with respective origin with respect to which internal loads are calculated.

8

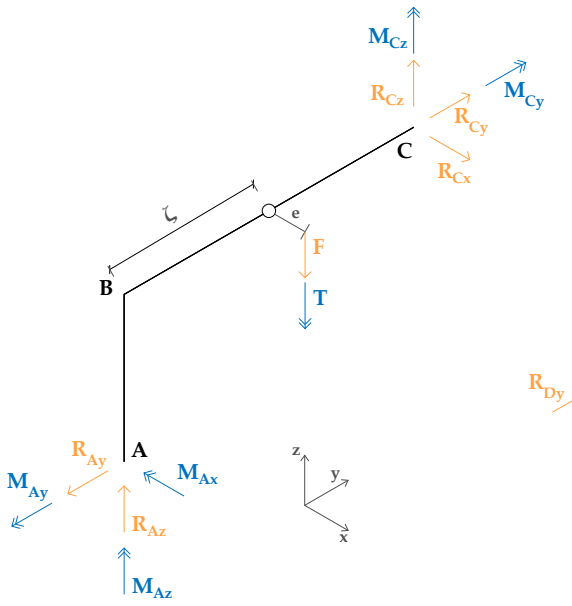
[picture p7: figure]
RAz; RAy; MAy; MAz; MAx; RCz; MCz; RCy; MCy; RCx; RDy

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
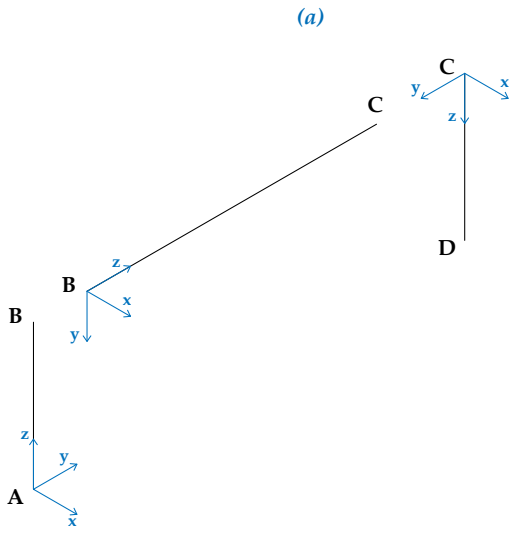
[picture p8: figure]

(b)

Figure 7: free body diagram (a) and reference frames (b) used for the description of the internal loads of the beam. In (a) the structure has been disassembled at the pivot point C in order to describe the reaction forces transmitted.

9

The full joint in B has not been described (as the connection preserves the continuity of the actions transmitted by the body), however the final design will imply the connection of two separate beams by means of a gusset.

After having written the Newton-Euler equations of the two bodies making the whole structure, we observe that only 11 out of 14 reactions forces are independent; chosen the hyperstatic variables X1 = MAz, X2 = MDy, X3 = MAx to reduce the problem to an isostatic one, the parametric definitions of the reaction forces is

RAz =

F(L − ζ) − X3
L

RCz = RDz =

Fζ + X3
L

MAy = MCy = X2 MCz = MDz = T − X1

Non mentioned actions are identically zero. To solve the hyper-static problem the Castigliano’s theorem has been used, computing the elastic energy Ue of the structure neglecting shear loads:

Ue =

3
∑

i=1

# Z li

0

N²
i
2EAi

+

M²
x,i
2EIxx,i

+

M²
y,i
2EIyy,i

+

M²
z,i
2GJt,i

!
dz

Assuming the generalized displacement related to the hyper-static variables is zero, solving the equations ∂Ue/∂X1 = 0 and ∂Ue/∂X2, the solution that we achieve is still depending on the geometrical parameters of the sections that are still unknown. To simplify the calculations, assuming that A1 gives

X1 = T | X2 = 0 | X3 = F

L − 2ζ
2

In this preliminary design phase in order to over-estimate the loads the the frame should bear a force F = 200N is considered (modelling the weight of about 20kg, related to all the carried equipment on the moving arm including batteries and filled water tank) and the nominal value of the torque T = 0.8N · m as in the requirements specification.

Choice of the standard beams With the preliminary design model described, different solutions can be found looking from various vendors present in the marker. In particular for the project main reference has been made to the Parker IPS catalogue [3] due to the high availability of accessories components, however similar product can be found by other vendors (as group we also evaluated 8020 [4] and Tslots by Bonnel Aluminum [2]). Data-sheets presents information about the section area A and second moments of area Ixx, Iyy respect the primary axes, however no information is given for the torsional rigidity Jt and so the related component is in the calculation neglected.
After an iterative process, table 3 shows the sections drawing and associated geometric properties of the chosen components for both elevated track and supporting beams. This choice determines a safety factor ϕ = 3.8 for the whole structure that’s a safe value for us; it is true that we neglected both shear and torque loads, and in practical applications other external and unexpected actions might act on the frame, however it is also true that the geometric simplification A1 in the solution of the hyperstatic problem heavily reduced the ability of the system to bear load (as we will see in the static verification).

10

Table 3: selected beams section chosen from the Parker IPS catalogue [3] and related main properties (area, moments of inertia and weight per unit length).

Area | Moments of inertia | Weight
Usage | A[cm² | ] Ixx[cm⁴
] | Iyy[cm⁴
] | ρ[kg/m] | Product code
track | 6.65 | 9.46 | 9.46 | 1.72 | 10-040
supports | 5.20 | 8.27 | 8.27 | 1.41 | 10-540

Sections for the track beam (on the left) and the supports (right).

As a side note, our design was forced to use the 40mm T-slot series (even if a 30mm profile would have let us achieve similar results with lower weights and costs) as it’s the only one that disposes off-the-shelf linear roller system that can be easily mounted and used (choosing other profile series would have ended in custom solution that’s undesired by the product design specifications).

### 4 Design process and verifications

With the data obtained from the preliminary analysis, the design has been carried using the 3D CAD software AutoDesk Inventor Professional with the help of the components library provided by the manufacturer Parker IPS. At this stage what we mainly did was to give shape at the chosen concept by using mechanical elements provided by the library only in order to minimize the need of custom-made parts.
For actuating the machine no off-the-shelf solution are available, hence we decided to create our custom rack design (INSERIRE E CREARE RIFERIMENTO AL DISEGNO): such component is made by a set of smaller bid that can be 3D printed with plastic material; such elements can be joined together by means of standard T-slot components. The rack is mounted on both tracks placed at the ground (motion in the x direction) and the elevated one (motion in the y direction); the gear attached to the motor that’s actuating the system is a standard element made out of steel. Proper static verification of the component will be described in the following pages.
Using the theory from the course we performed a static verification of the machine and we verified two critical bolted joints.

11

### 4.1 Static verification

With all the geometrical values known, it has been possible to carry out a more detailed analysis. Considering a more complex model of the forces that takes into account also the distributed load due to the gravity and that the force F is applied with an eccentricity e = 5cm, it has been possible to parametrically define the hyperstatic variables as

X1 ≃

0.63 − 0.16ζ
N · m X2 ≃ −8.10 N · m

X3 ≃

− 10.54 − 11.07ζ + 55.53ζ
| 2 − 6.17ζ
| 3
| N · m

Evaluating the stress state on the 3 beams making up the structure for values of ζ ∈ [0, L], what we obtained is that the most critical section is in the elevated track for ζ

∗ = 1.65m at z

∗ = 1.65m where the maximum bending value M∗ x ≃ 135.64N · m is
achieved. Knowing that N∗ = 0 and neglecting the shear stress contribution due to both shear V

∗

y ≃ 111N and torque M∗
z ≃ 1.89N · m, the stress state is

σzz(y) = M∗
x
Ixx,track
y | ⇒ | σzz,max = σzz(2cm) ≃ 28.68MPa

This leads to a safety factor of ϕ = σys/σzz,max ≃ 8.37, meaning that the structure is statically verified. This value is more then twice than the one achieved in the preliminary design phase but is due to the fact that in this case the full analytical solution of the hyperstatic problem has been considered, having determined all geometrical properties of the sections. As a reminder:

- due to the lack of analytical formulas for such complex geometry section, shear components due to torque and shears are neglected and could have influenced the mechanical system;
- we did not consider external forces acting that might act on the global x axis due to the actuation of the machine or accidental load applied by the end user: this can lead to an increase in bending and torques that might make the system fail.

MAGARI AGGIUNGERE GRAFICI DEL MOMENTO IN FUNZIONE DI 2/3 VAL-ORI DI ζ
AGGIUNGERE LA STIFFNESS VERIFICATION

### 4.2 Fatigue verification

Most critical section As already stated, the most critical section is subjected to a maximum stress of σmax ≃ 28.68MPa. While functioning we expect that the turret performing the operation to the soil periodically moves along the track: having ζ varying over time determines that also the internal loads are fluctuating and this might arise fatigue failure of the machine.
Given the need of a fatigue verification, acknowledged that the minimum bending load at z

∗
is Mx,min ≃ 14.05N · m achieved for ζ = 0m, determining σmin ≃ 2.97MPa; this further implies that the mean and amplitude stresses for fatigue verification are

σm ≃ 15.82MPa σa ≃ 12.85MPa

12

According to Soderberg criterion, the equivalent amplitude only stress component evaluates to

σa,eq =

σysσa
σys − σm

≃ 13.76MPa

In this case the load factor is Cl = 1; given an equivalent diameter deq =

q
4
π A = 29mm,
the corresponding size factor is Cd = 1.189d

−0.097
eq ≃ 0.86; details concerning the surface finish of the T-slot beams are not enough to fully determine the surface coefficient Cs that’s assumed in this case to be 0.8 as safety value. Considering an endurance limit of the 6061-T5 aluminium alloy of σlim = 100MPa [5], this means that the safety factor against fatigue failure is

ϕfatigue = CsCdCl

σlim

σa,eq

≃ 4.98

### 4.3 Threaded joints verification

Preliminary design

Given the customer’s requirements, the threaded fasteners used for the threaded joints in the whole robot are chosen to be standard screws with diameter of 8mm, compatible with the 40mm T-slot profiles.
Considering the threaded joints present on the robot, the maximum thickness of the members is given by the sum between the beam cross section’s width, 40mm, and the machined gussets thickness, 8mm. Given that two screws must fit, as in section A, the length of the screws is chosen to be equal to 18mm, according to UNI ISO 888; table 4 reports the main properties of the chosen bolt used for the verification of the connections.

Table 4: selected bolt chosen from the Parker IPS catalogue [3] and related main properties.

Parameter symbol | value
diameter | d | 8mm
head diameter | d0 | 14mm
length | l | 18mm
cross-section | Ab | 16πmm²
tensile cross-section | Abt | 36.6mm²
ultimate tensile strength | σuts | 505MPa
product code | 24-118-8

With reference to Figure 6, threaded joints are present in sections A, B, C and D. The verifications are carried out with respect to the most critical sections which, according to the load analysis performed previously, are identified as section A and D. Moreover, since the load distribution depends on the position of the point of application of the external load, the most critical condition corresponds to the one in which the load is applied in ζ = 1 for section A and ζ = 3 for section D.

13

Section A

The loads applied on section A are the following:

- axial load NA = −251.13N;
- bending moment MxA = −12.65N · m;
- bending moment MyA = 1.89N · m;
- torque MzA = −0.59N · m.

In correspondence of section A, there are two machined gussets chosen from the Parker IPS catalogue [3], reported in figure 8. Given the geometry of the component, the threaded joints are positioned on the vertical z and horizontal x global axis. For this reason, two separated analysis are performed.

Figure 8: machined gusset, code 10-102, from the IPS catalogue [3]. In the drawing: A = 77mm, B = 77mm, C = 34mm, D = 20mm, E = 40mm, F = 8mm, G = 9mm.

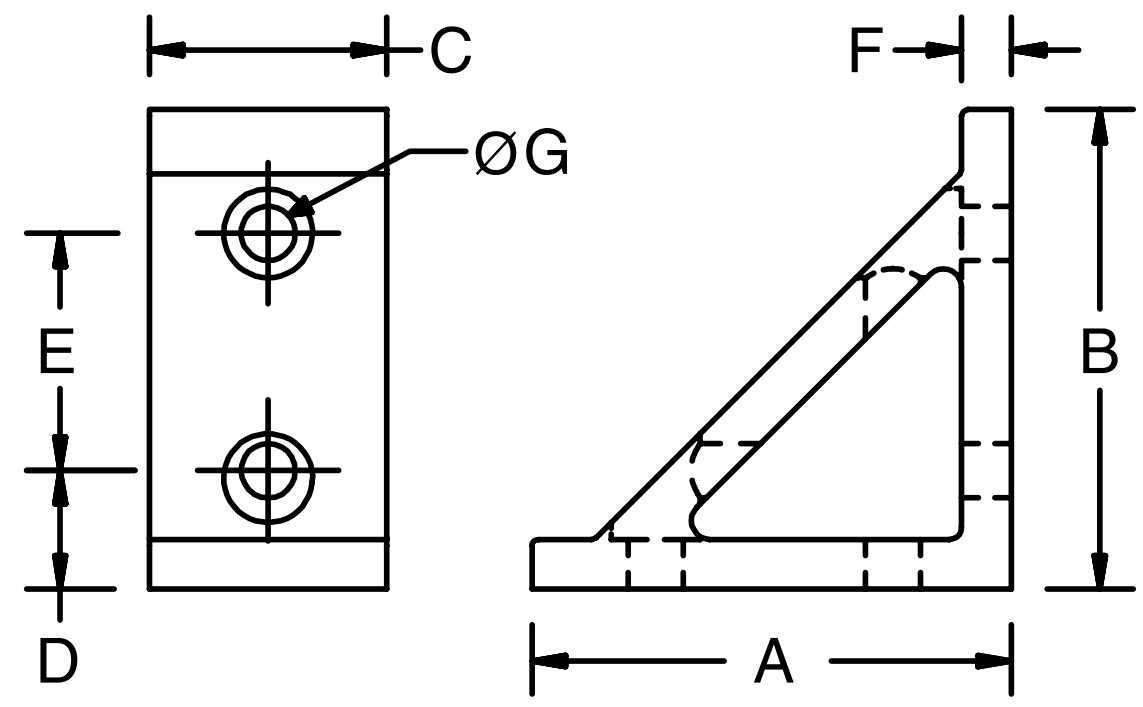
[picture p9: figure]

Threaded joints along the x axis The loads acting on section A the x axis are represented in figure 9.
The sliding actions are given by the torque MzA, which produces a shear force on every

Figure 9: Loads on section A, along the x axis.

screw equal to:

Vi =

Mz1ri
nb
∑
i=1

r

2
i

where ri are the distances of every screw from the center of the section, and are equal to r1 = 40mm, r2 = 80mm. The shear force is calculated for the most critical screws, distant r2 , and it is equal to:

V2 =

MzAr2
2r

2
1 + 2r

2
2

= −2.97N

The shear and punching resistance verifications can be performed as follow:

14

- shear resistance verification: |V2| <

σutsAb
ϕ
where σuts corresponds to the screw’s ultimate tensile strength, Ab

to the bolt cross-section and ϕ is the safety factor which, according to Eurocode3, is equal to 1.25
0.58 .
As a consequence, it follows that:

σuts >

|V2|ϕ
Ab

= 0.13MPa

- crushing resistance verification:

|V2| <

σuts,mdt
ϕ

where σuts,m corresponds to the member’s ultimate tensile strength, d to the bolt diameter and ϕ is the safety factor which, according to Eurocode3, is equal to 0.5. Finally, t corresponds to the member’s thickness, which can be calculated as the sum of the machined gusset thickness, F = 8mm, and the base’s thickness, equal to 16mm:

σuts,m >

|V2|ϕ
dt = 7.73 · 10⁻³MPa

Separating actions are given by the axial load and the bending moments.
Assuming that the members are rigid it is possible to calculate the effects of the separating actions in both xz and yz planes.
The load caused by the separating action, acting on each bolt can be calculated as:

Ni =

Mbhi
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
Considering the xz plane and assuming that the pivot is placed on the edge of the section, the constant hi will be equal to:

h1 = 17mm
h2 = 57mm
h3 = 137mm
h4 = 177mm

The normal load is calculated for the most critical screw as follow:

Nxz =

MyAh4
h

2
1 + h

2
2 + h

2
3 + h

2
4

+

N1
nb

= −56.53N

Since the axial load acting on every bolt is negative, i.e. the bolt are subjected to compression, there are no issues relative to tension and punching resistance. As a consequence, it is not necessary to perform those verifications.

15

Considering the yz plane and assuming that the pivot is placed on the edge of the section, the constants hi will be all equal to h = C
2 = 17mm. The normal load is equal to:

Nyz =

MxAh
4h

2 +

N1
nb

= 123.18N

The tension resistance and punching verification can be performed as follow:

- tension resistance verification:

Nyz <

σutsAbt
ϕ

Where σuts corresponds to the screw’s ultimate tensile strength, Abt to the bolt tensile cross-section and ϕ is the safety factor which, according to Eurocode3, is equal to 1.25
0.9 . As a consequence, it follows that:

σuts >

Nyzϕ

Abt

= 4.67MPa

- punching resistance verification:

Nyz <

πd0tσuts,m
ϕ

Where σuts,m corresponds to the member’s ultimate tensile strength, d0 the bolt head diameter and ϕ is the safety factor which, according to Eurocode3, is equal
to 1.25
0.6 . Finally, t corresponds to the member’s thickness, which can be calculated as the sum of the gusset’s thickness, F = 8mm, and the base’s thickness, equal to 16mm:

σuts,m >

Nyzϕ

πd0t

= 0.24MPa

Threaded joints along the z axis The loads acting on section A the z axis are represented in figure 9.
In this case the sliding actions are given by MxA and NA which produce a shear force

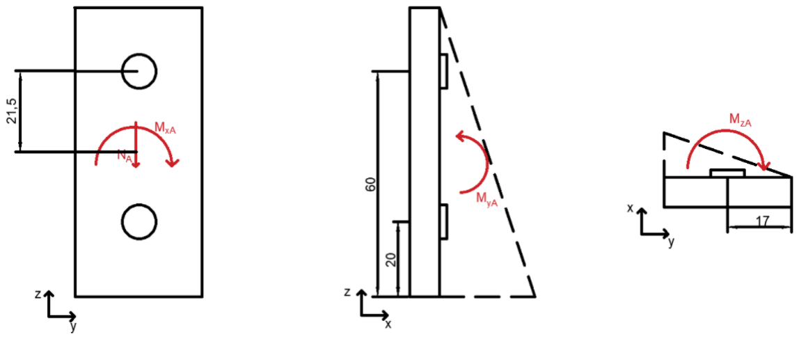
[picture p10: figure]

Figure 10: Loads on section A, along the z axis.

16

on every screw equal to:

Vi =

MxAri
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
where ri are the distances of every screw from the center of the section, and are equal to r = 21.5mm.
V =

MxAr
2r

2 +

NA
2

= 140.41N

- shear resistance verification:

σuts >

Vϕ
Ab

= 6.20MPa

- crushing resistance verification:

σuts,m >

Vϕ
dt = 0.18MPa

The separating actions, MyA and MzA generates normal load on each and the effects are studies as previously for yz and xy plane.

Ni =

| Mbhi
| nb
∑
| i=1

h

2
i

+

N
nb

Considering the yz plane and assuming that the pivot is placed on the edge of the section, the constants hi will be equal to h1 = D = 20mm and h2 = D + E = 60mm. The normal load is evaluated for the most critical screw and is equal to:

Nxz =

| MyAh2
h

2
| 1 + h

2
1

= 28.40N

- tension resistance verification:
σuts > | Nyzϕ
| Abt

= 1.08MPa

- punching resistance verification:

σuts,m >

| Nyzϕ
| πd0t

= 27.46 · 10⁻³MPa

Finally, considering the xy plane, assuming that the pivot is placed on the edge of the section, the constants hi will be all equal to h = C
2 = 17mm the normal load is equal to:

Nxy =

MzAh
2h

2 = 17.47N

- tension resistance verification:

σuts >

Nxyϕ
Abt | = 0.66MPa.
- punching resistance verification:

σuts,m >

Nxyϕ πd0t | = 16.89 · 10⁻³MPa.

17

Section D

The loads applied on section D are the following:

- axial load ND = 233.01N;
- bending moment MxD = 0N · m;
- bending moment MyD = 8.11N · m;
- torque MzD = −0.59N · m.

In correspondence of section D, there is a pivot joint chosen from the Parker IPS catalogue [3], reported in figure 11. The loads action on section D are reported in figure 12

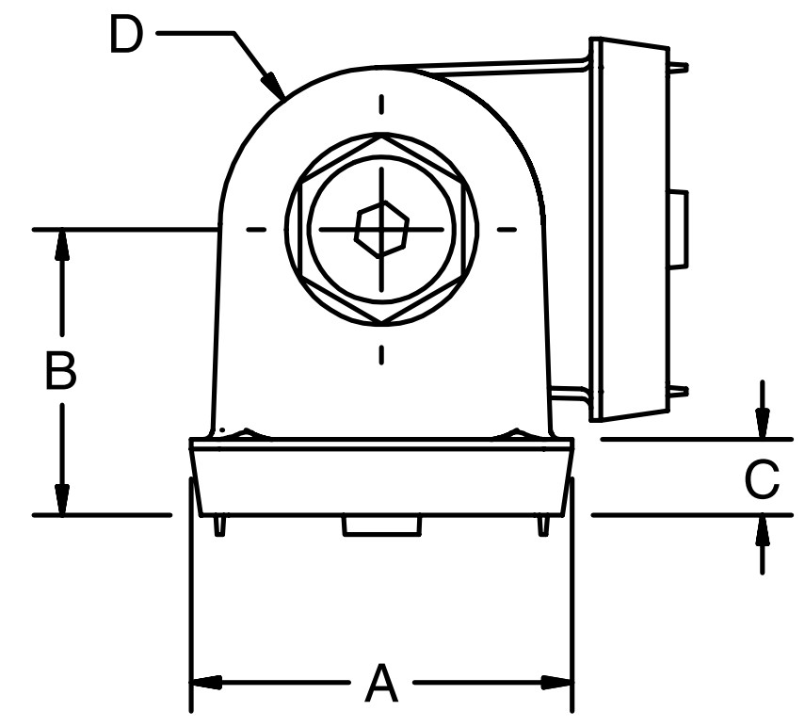
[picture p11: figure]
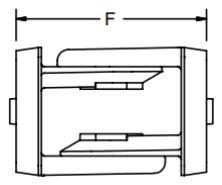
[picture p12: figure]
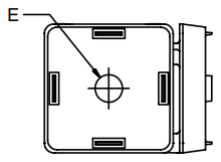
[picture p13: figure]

Figure 11: pivot joint, code 23-010, from the IPS catalogue [3]. In the drawing: A = 40mm, B = 30mm, C = 9mm, D = 40mm, E = 8.5mm, F = 60mm.

Figure 12: loads acting on section D

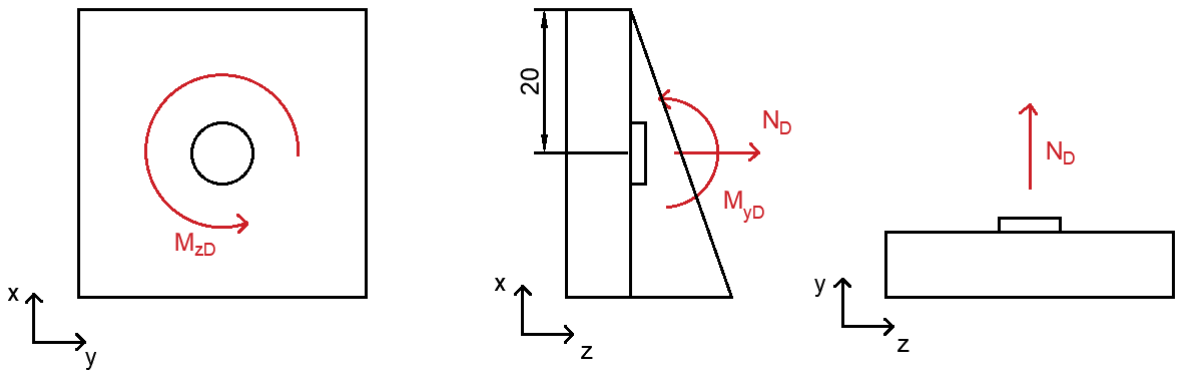
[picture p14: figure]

In this case, the sliding actions are given by the torque MzD, figure 11(b). However, since there is a single screw positioned in the center of the section, they do not cause any shear on the screw. (??)
Separating actions are given by the axial load and the bending moments. Assuming that the members are rigid it is possible to calculate the effects of the separating actions in both xz and yz planes. The load caused by the separating action, acting on the screw can be calculated as:
Ni =

Mbhi
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
where hi
is the distance of the i-th bolt from the pivot point.

Nxz =

MyD
h

+ ND = 638.33N

18

Considering the xz plane and assuming the pivot on the edge of the section, h is equal to A
2 = 20mm. The tension resistance and punching verification can be performed as follow:
- tension resistance verification:

Nxz <

σutsAbt
ϕ

Where σuts corresponds to the screw’s ultimate tensile strength, Abt to the bolt tensile cross-section and ϕ is the safety factor which, according to Eurocode3, is equal to 1.25
0.9 . As a consequence, it follows that:

σuts >

Nxzϕ

Abt

= 24.22MPa

- punching resistance verification:

Nxz <

πd0tσuts,m
ϕ

Where σuts,m corresponds to the member’s ultimate tensile strength, d0 the bolt head diameter and ϕ is the safety factor which, according to Eurocode3, is equal
to 1.25
0.6 . Finally, t corresponds to the member’s thickness, which can be calculated as the sum of the pivot joint thickness, C = 9mm, and the member’s cross section, equal to 40mm:

σuts,m >

Nxzϕ
πd0t

= 0.62MPa

Considering instead the xz plane we have:

Nyz =

MxD
h

+ ND = 233.01N

thus:

- tension resistance verification:

Nyz <

σutsAbt
ϕ

⇒ σuts >

Nyzϕ

Abt

= 8.84MPa

- punching resistance verification

Nyz <

πd0tσuts,m
ϕ
⇒ | σuts,m >

Nyzϕ

πd0t

= 0.23MPa

In conclusion, the bolt ultimate strength must be greater than 24.22MPa, a value that allows to choose any bolt property class. In order to minimize the costs, property 4.6 is chosen.(????)
Moreover, the verifications for crushing and punching provide the minimum member ultimate strength, σuts,m > 0.23MPa, value much smaller than the chosen member’s UTS.
Note that for the verifications of the separating actions the rigid member approach was used, which is usually more conservative than the others. However, since the values

19 obtained are far distant from the one of the selected materials, there is no need of a more precise verification.
As for most applications, the preload used to tighten the bolts is chosen to be 80% of the yield strength. At this point, the tensile joint verification should be performed. However, due to the low external loads acting on the bolts, no issue will arise and there is no need to carry out this analysis.

### 4.4 Design and static verification of rack and gear

The verification continued with the parts responsible for actuating the machine, rack that is positioned on both tracks and gear attached on the motors’ shaft. We focused on two important aspects, interference and tooth root bending resistance.

Interference condition

It’s fundamental to check if this condition is fulfilled, because otherwise we could have a problem of undercut, when the tip of the rack cutter is moved beyond the base circle of the gear and the result is the weakening of the gear’s teeth.
Interference condition is function of the minimum number of teeth of the pinion, in accordance with the following equation:

zmin =

2
sin²α
, | (1)

where α is the pressure angle, as we can see in figure 13. In our case we designed the

Figure 13: standard rack and pressure angle α.

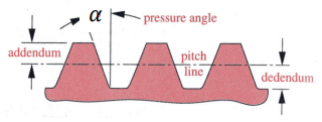
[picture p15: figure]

profile with a pressure α = 20◦ , thus we have:

zmin = 17,

Gear design and verification

The gear attached to the motor’s shaft is designed choosing as number of tooth z = 18; assuming that the motors actuating the machines can generate a power P = 10W at n = 50rpm, the associated maximum generated torque is T = 1.9N · m. Choosing as module m of the gear the value 2mm, then the nominal diameter of the gear is d = zm = 36mm and the maximum force that can be transmitted by the gear is

F =

T
r

= 2

T
d

= 106N

20

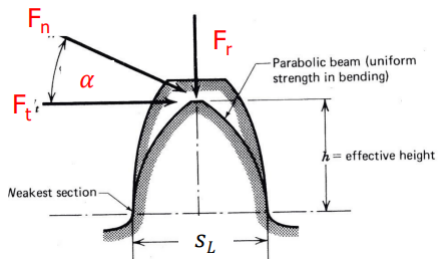
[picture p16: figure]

(a)

(b)

Figure 14: tooth details: section (a) and face width (b).

Tooth root fatigue resistance One of the most important problem in the usage of gears is the teeth fatigue resistance, due to the fact they’re subjected to pulsating loads. In our analysis we used the Lewis method that consider the tooth as a cantilever beam and shear and compressive normal stresses are neglected.
According to such theory, the stress state acting on the tooth is

σ =

F
mbYl

where b is the face width (figure 14) and Yl
is the Lewis factor taking into account for the shape of the tooth; such parameter depends on both the number of teeth z and the pressure angle α, and for the given data it evaluates to Yl = 0.308.
Given the ultimate tensile strength σuts = 40MPa of plastic materials used in 3D printing machine and choosing a safety factor ϕ = 2, reversing the Lewis equation gives us the minimum face width:

σ ≤

σuts
ϕ

⇒ b ≥

Fϕ

Ylmσuts

= 8.61mm

thus a width b = 10mm for the teeth has been chosen.

Crushing verification The gear is mounted to the motors shaft by means of a built-in parallel key; the shaft is made of steel with high mechanical properties, while the gear, that can be 3D-printed, has lower stress capability, thus we need to verify the connection at crushing.
By the geometry of the gear reported in the annexes, the contact surface that is used to exchange the load is a rectangular surface of dimensions b × h = 10mm × 1.292mm; given the force F that has to be exchanged, the mean pressure at the contact surface is

p =

F
| bh = 8.21MPa

Considering the allowable pressure pall = σuts = 40MPa, then the safety factor against crushing of the gear is ϕ = 4.87.

21

### A Appendix

A.1 Materials

Table A.1.1: list of available aluminium alloys for T slot profiles with relative mechanical properties (based on ASTM B-221 standard) and extruded profile vendor that provides this results.

ASTM code | σuts[MPa] σys[MPa] E[GPa] | ν[·] | usage | vendors
6005-T5 | 262 | 241 | 70 | 0.33 | profiles | Parker
6105-T5 | 262 | 241 | 70 | 0.33 | profiles | 80/20, Parker
6061-T6 | 262 | 241 | 70 | 0.33 | accessories | Parker
6063-T6 | 206 | 172 | 70 | 0.32 | profiles, ac-
| | | | | cessories | Parker
6065-T6 | 206 | 172 | 68 | 0.32 | profiles | tslots

Parameters of the table: σuts ultimate tensile strength, σys yielding strength, E Young’s module, ν Poisson’s ratio.
σuts and σys are taken directly from the ASTM B-221-05 [6] standard while other parameters came from T-slot producer’s data-sheets [2] [3] [4].

22

A.2 Bill of materials

Table A.2.1: bill of material and estimated costs.

Code Product | Quantity | Price
Manufacturer
XXX | General piece | 1 | €—
XXX | General piece | 1 | €—
Manufacturer
XXX | General piece | 1 | €—
XXX | General piece | 1 | €—
Total: €100.00

INFORMAZIONI SU DOVE SONO STATI PRESI I PREZZI

23

A.3 Technical drawings

A.3.1 Gear and rack design

In the following page the detailed representation of the custom created rack and gear design is reported.

24

6,28

1,69 R0,90

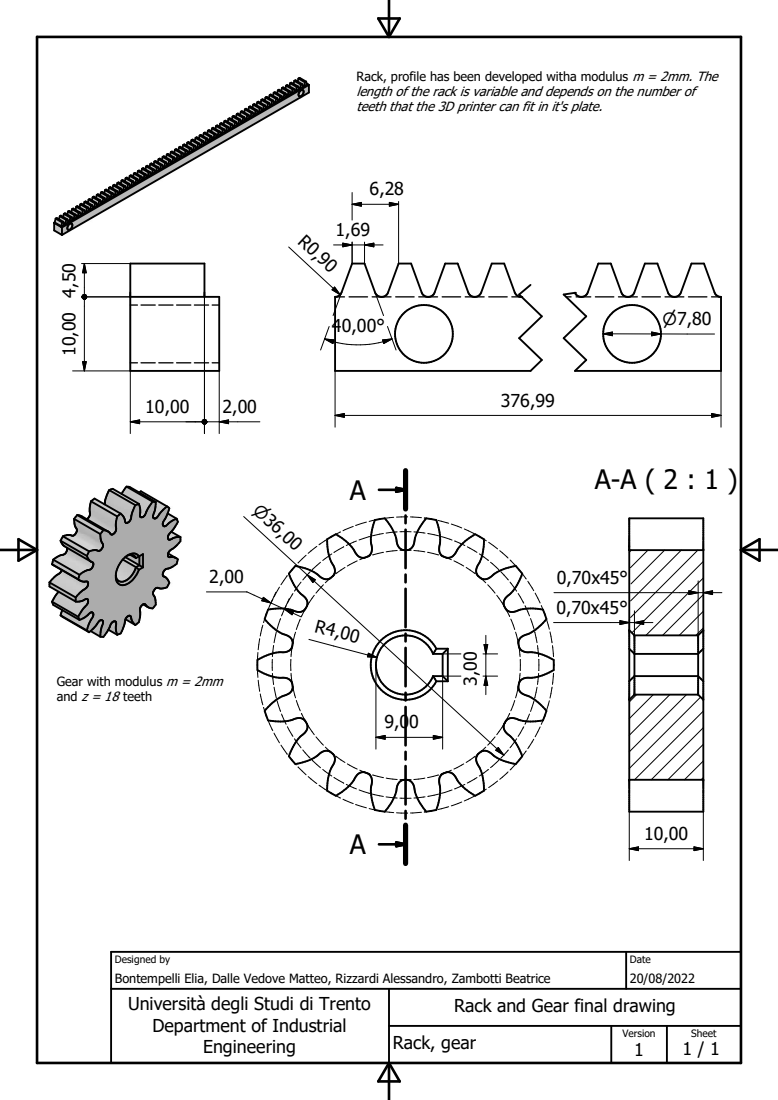
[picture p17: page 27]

Rack, profile has been developed witha modulus m = 2mm. The
length of the rack is variable and depends on the number of
teeth that the 3D printer can fit in it's plate.

Gear with modulus m = 2mm
and z = 18 teeth

Designed by Bontempelli Elia, Dalle Vedove Matteo, Rizzardi Alessandro, Zambotti Beatrice | Date 20/08/2022
Università degli Studi di Trento Department of Industrial Engineering | Rack and Gear final drawing

Rack, gear | Version 1 | Sheet 1 / 1

### B Bibliography and references

In order of first appearance:

[1] MindsHub Association. Progetto CyberOrto. url: https://mindshub.it/progettocyberorto/. (https://mindshub.it/progetto-cyberorto/)
[2] Complete Catalog. V. 6. Tslots by Bonnell Aluminum. 2021.
[3] Parker Industrial Profile Systems. T-Slot Aluminum Framing. Rev. 5. Parker Hannifin Corporation. 2021.
[4] Custom Aluminum Framing Systems. Catalog 23, Part No. L1019. 80/20 Inc. 2019.
[5] Maxim Murashkin et al. “Fatigue Behavior of an Ultrafine-Grained Al-Mg-Si Alloy Processed by High-Pressure Torsion”. In: Metals - Open Access Metallurgy Journal (April 2015).
[6] ASTM. ASTM B-221-05 - Standard Specification for Aluminum and Aluminum-Alloy Extruded Bars, Rods, Wire, Profiles, and Tubes. ASTM B-221-05. ASTM, 2005.

26

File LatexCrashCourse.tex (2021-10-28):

\section{Latex Crash Course}
	Così io scrivo normalmente e posso fare un testo; per andare a capo semplicemente posso fare così \\ come potete vedere
	
	Lasciando una riga vuota di codice ho creato un nuovo paragrafo. Se voglio scrivere un parametro matematico in linea di testo basta che faccio $f_l(x) = 10N$, mentre se voglio un'equazione bella centrata:
	\begin{equation}
		f_{x, max} (t) = \int_{-\infty}^{\frac \pi 2} e^{-t^2} \, dt
	\end{equation}
	Se invece non voglio avere il numero per l'equazione basta fare 
	\[ f(x,y) = \cos(x) \sin(y) \]
	
	Adesso faccio un'equazione per usare i riferimenti:
	\begin{equation} \label{eq:esempioequazione}
		f(x) = e^x
	\end{equation}
	Quella appena scritta è l'equazione \ref{eq:esempioequazione} e si trova a pagina \pageref{eq:esempioequazione}.
	
	\paragraph{Elenchi puntati} Con questo comando posso creare un nuovo paragrafo con un certo titolo e farvi vedere come fare gli elenchi puntati:
	\begin{itemize}
		\item il primo punto;
		\item il secondo punto
	\end{itemize}
	L'elenco numerato si fa invece scrivendo
	\begin{enumerate}
		\item il primo punto;
		\item il secondo punto
	\end{enumerate}
	
	Per scrivere in corsivo basta fare \textit{così, usando il comando "textit"} mentre \textbf{per il grassetto utilizzo "textbf"}. Volendo \textbf{\textit{posso anche usarli insieme}}.

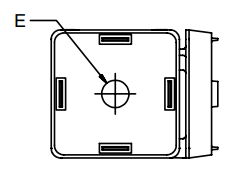
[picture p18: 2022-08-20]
Images/pivot1.png

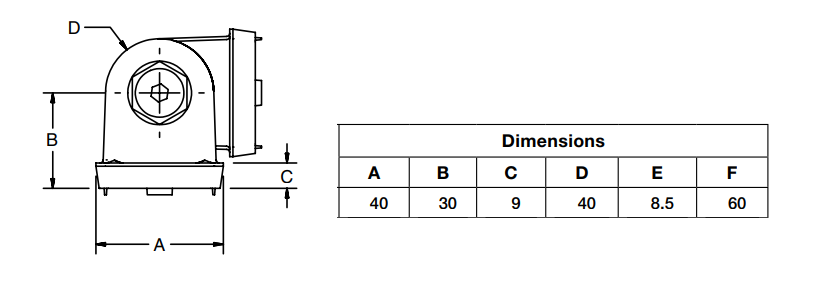
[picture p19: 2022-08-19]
Images/pivotjoint.png

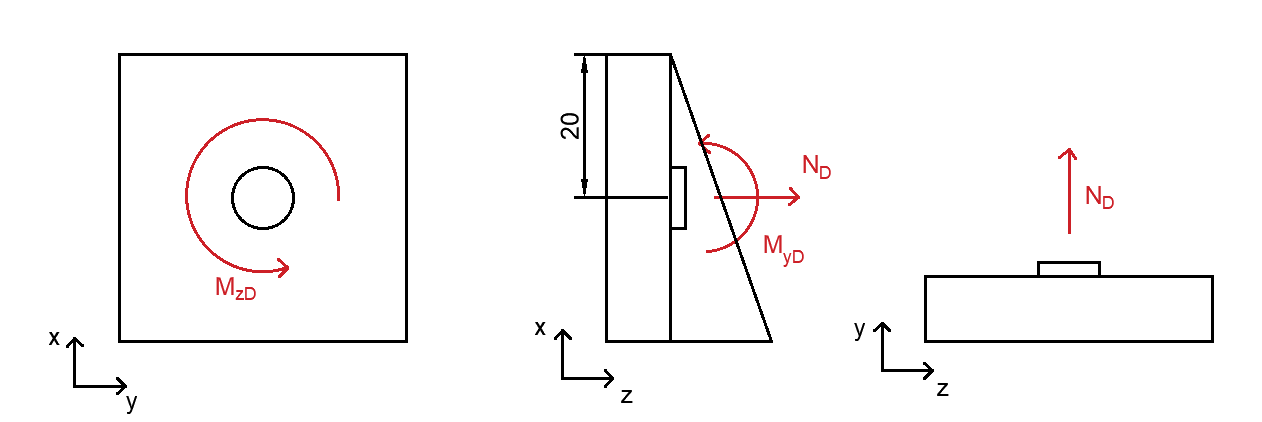
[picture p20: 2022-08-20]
Images/loadssectionD.png

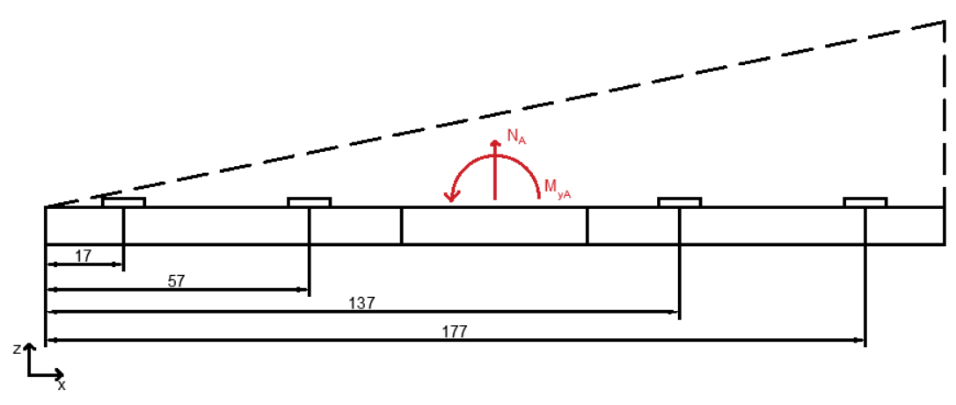
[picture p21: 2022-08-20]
Images/xzA_assex.png

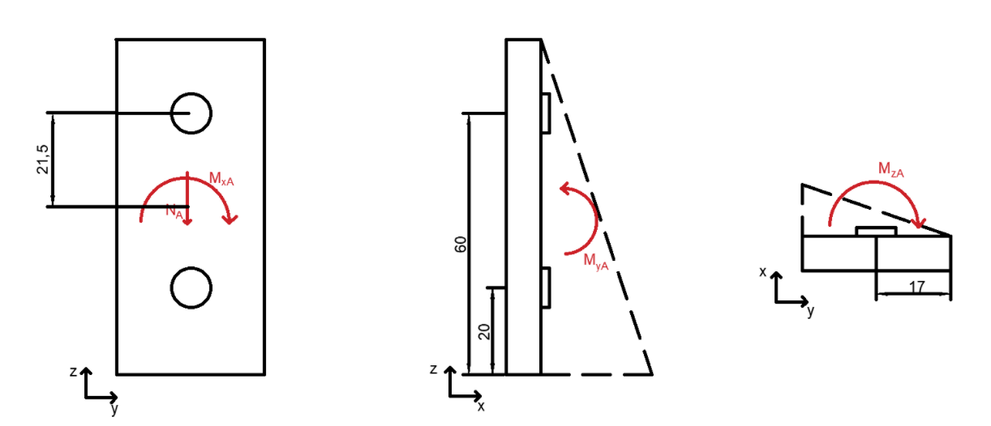
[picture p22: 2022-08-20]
Images/assez_A.png

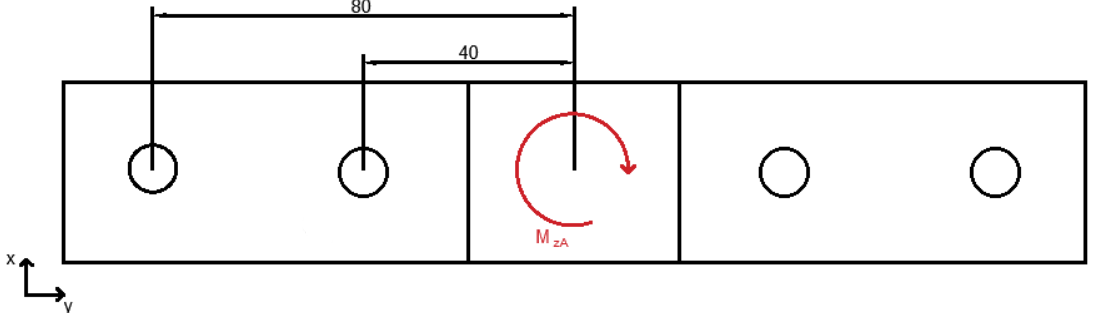
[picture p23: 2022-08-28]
Images/xyA_assex.png

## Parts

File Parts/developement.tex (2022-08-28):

\section{Design process and verifications}
	With the data obtained from the preliminary analysis, the design has been carried using the 3D CAD software \texttt{AutoDesk Inventor Professional} with the help of the components library provided by the manufacturer Parker IPS. At this stage what we mainly did was to \textit{give shape} at the chosen concept by using mechanical elements provided by the library only in order to minimize the need of custom-made parts.
	
	For actuating the machine no off-the-shelf solution are available, hence we decided to create our custom rack design (see \ref{draw:gearrack}, page \pageref{draw:gearrack}): such component is made by a set of smaller bid that can be 3D printed with plastic material; such elements can be joined together by means of standard T-slot components. The rack is mounted on both tracks placed at the ground (motion in the $x$ direction) and the elevated one (motion in the $y$ direction); the gear attached to the motor that's actuating the system is also 3D printed and is attached to the motor  shaft by means of a key. Proper static design and verification of the component will be described in the following pages.
	
	Using the theory from the course we performed a static verification of the machine and we verified two critical bolted joints.
	
	\input{Parts/static-verification}
	\input{Parts/fatigue-verification}
	\input{Parts/threadedjoints-verification}
	\input{Parts/rackgearverification}

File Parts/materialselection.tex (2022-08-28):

\subsection{Material selection}
	
	The main structural components are beams that, for client requirements, should be standard and so for this reason T-slot extruded aluminium profiles (figure \ref{fig:tslot:crosssectionexample}) are chosen after the following considerations:
	\begin{itemize}
		\item better volume-to-price ratio and lower density (respect to inox steels), so reducing costs associated to the spare parts and shipping;
		\item availability in the market: there are a lot of vendors that provide profiles with various geometrical dimensions, different aluminium alloys and surface finishes. This spare parts can be easily accessed by every private costumer;
		\item for T-slot extruded profiles lots of auxiliary components (such supporting brackets, fasteners, hinges...)  are provided from the same profiles manufacturers, reducing the need of custom made part and so decreasing the overall costs.
	\end{itemize}

	This elements can be also purchased with an anodized finish that allows to improve the corrosion resistance, increasing so the expected life time of the product in uncontrolled outdoor environment. Moreover the choice of aluminium is an environmentally friendly decision as it can be easily recycled at the end of life of the structure.
	
	\begin{SCfigure}[1.5][bh]
		\centering
		\caption{technical drawing of a T-slot profile's cross-section. The particular sketch represent the model \texttt{TS40-40LM} by Tslots \cite{tslot-ds}.}
		\label{fig:tslot:crosssectionexample}
	\end{SCfigure}
	
	\paragraph{Mechanical properties} For the design phase the following mechanical properties are considered: ultimate tensile strength $\sigma_{uts} = 260 MPa$, yielding strength $\sigma_{ys} = 240 MPa$, Young's module $E = 70 GPa$, Poisson's ratio $\nu = 0.32$; this values are chosen according to table \ref{tab:beammaterial} (page \pageref{tab:beammaterial}) as  they represent a lower bound (implying higher safety in calculations) for the aluminium materials properties used by T-Slot manufacturers.

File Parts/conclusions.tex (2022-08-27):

\section{Conclusions}
	The final robot is far from being finished, but this works provides a solid starting point to improve the actual machine design. At the current development state it has not been fully decided the final model of the motor used to actuate the system, however such decision will determine just a slight variation in the design of the plate used to connecting the motor to the plate of the linear guide; for this reason, the plate has not been reported in the technical drawings.
	
	The designed assembly is also provided with a roller system running on the elevated track where the turret performing the operation can be built up on containing all the required tools.
	
	For what concerns the actuation of the system, we assumed that the machine will be controlled in open loop using stepper motors; for this reasons at the end of all tracks a touch sensor need to be mounted in order to provide the control system (that will be an \texttt{Arduino} micro controller) with a reset point to rely on. \\
	Such sensors can be positioned at one side of the ground tracks where a resting station should be designed, providing the turret a safe place to charge the battery placed on board of the turret and that guarantees protection from external actions.
	
	\paragraph{Design improvements ideas} The proposed design still leaves room for further improvement.
	One thing that might be improved is the kit shipping capability: as we can see in the final bill of materials (appendix \ref{tab:BOM}, page \pageref{tab:BOM}) we have 3 main big components with a length greater then $3m$, making their transportation and handling difficult. One way to improve the design is by studying proper axial connections in order to join beams with smaller lengths while still not impacting the design of the gear-rack coupling and leaving proper clearances for the roller linear guides.

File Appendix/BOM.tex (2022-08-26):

\begin{table}[p]
	\subsection{Bill of Materials}
	\rule{\linewidth}{2pt}
	\caption{bill of material.}
	\label{tab:BOM}
	\rule{\linewidth}{1pt} \vspace{0mm}	
	
	\begin{center}
	\begin{tabular}{l p{7.3cm} c}
	\textbf{Code} & \textbf{Product} & \textbf{Quantity} \\ \hline
	\multicolumn{3}{c}{IPS Parker} \\
		\texttt{10-540} & 40mm light T-slot profile & $1 \times 700mm$ \\
		\texttt{10-540} & 40mm light T-slot profile & $1 \times 560mm$ \\
		\texttt{10-040} & 40mm T-slot profile & $1\times 3\,000mm$ \\
		\texttt{10-340} & 40mm tri-slot profile & $2\times 4\,000mm$ \\
		\texttt{10-081$^1$} & 16$\times$80mm profile & $3\times 300mm$ \\
		\texttt{20-102} & machined gusset & $3$ \\
		\texttt{23-010} & pivot join & $2$ \\
		\texttt{30-401} & linear shaft roller components & $12$ \\
		\texttt{13-505} & " & $1\times 3\,000mm$ \\
		\texttt{13-106} & " & $1\times 3\,000mm$ \\
		\texttt{13-505} & " & $2\times 4\,000mm$ \\
		\texttt{13-106} & " & $2\times 4\,000mm$ \\
		\texttt{20-058} & M8 T-nut & $14$ \\
		\texttt{20-049} & M8 double T-nut  & $33$$^3$ \\
		\texttt{20-050} & M8 double T-nut  & $15$ \\
		\texttt{24-116-8} & M$8\times1.25$ button head screw, length $16mm$ & $14$ \\
		\texttt{24-118-8} & M$8\times1.25$ button head screw, length $18mm$ & $12$ \\
		\texttt{24-120-8} & M$8\times1.25$ button head screw, length $20mm$ & $2$ \\
		\texttt{24-130-8} & M$8\times1.25$ button head screw, length $30mm$ & $4$ \\
		\texttt{24-212-8} & M$8\times1.25$ flat head screw, length $12mm$ & $4$ \\
		\texttt{24-320-4} & M$4\times0.8$ socket head screw, length $20mm$ & $61$$^3$ \\
		\texttt{24-330-8} & M$8\times1.25$ socket head screw, length $30mm$ & $16$ \\
		\texttt{24-708} & M8 spring washer & $28$ \\
		\texttt{24-708} & M8 spring washer & $28$ \\
	\multicolumn{3}{c}{Undefined manufacturer} \\
		\texttt{AS 1474 - M4}$^2$ & Hexagonal nut & $12$ \\ 
		\texttt{ISO 1580 M4x12}$^2$ & Button head screw & $12$ \\ 
		& M$8\times1.25$ male to M$4\times0.7$ female thread reducer & $54$$^3$ \\
	\multicolumn{3}{c}{3D printed parts} \\
			& Gear & $3$$^3$ \\ 
			& Rack & $28$$^3$ \\ 			
%	\multicolumn{3}{c}{Undefined manufacturer} \\
%			\multicolumn{2}{r}{\textbf{Total:}} & \texteuro 100.00
		\end{tabular}
	\end{center}
	
	\vspace{3mm}
	\rule{\linewidth}{1pt}
	{
		\scriptsize
		$^1$: the piece need requires need to be machined in order to create the holes for inserting the socket head screws. \\
		$^2$: this component might change depending on the final motor chosen to drive the system. \\
		$^3$: the number might change depending on the size of the 3D printed rack; in this case it has been considered a component with $z=60$ teeth, equivalent to a $377mm$ nominal length.
	}	
	
	\rule{\linewidth}{2pt}
	
\end{table}

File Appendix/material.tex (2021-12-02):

\subsection{Materials}
\begin{table}[h]
	\rule{\linewidth}{2pt}
	\caption{list of available aluminium alloys for T slot profiles with relative mechanical properties (based on \texttt{ASTM B-221} standard) and extruded profile vendor that provides this results.}
	\label{tab:beammaterial}
	\rule{\linewidth}{1pt} \vspace{0mm}	
	
	\begin{center}
		\begin{tabular}{r| c c c c | p{2cm} | l}
			ASTM code & $\sigma_{uts} [MPa]$ & $\sigma_{ys} [MPa]$ & $E[GPa]$ & $\nu [\cdot]$  & usage & vendors \\ \hline 
			6005-T5 & 262 & 241 & 70 & 0.33 & profiles & Parker \\
			6105-T5 & 262 & 241 & 70 & 0.33 & profiles & 80/20, Parker \\
			6061-T6 & 262 & 241 & 70 & 0.33 & accessories & Parker \\
			6063-T6 & 206 & 172 & 70 & 0.32 & profiles, accessories & Parker \\
			6065-T6 & 206 & 172 & 68 & 0.32 & profiles & tslots
		\end{tabular}
	\end{center}
	
	\vspace{3mm}
	\rule{\linewidth}{1pt}
	{
		\scriptsize
		Parameters of the table: $\sigma_{uts}$ ultimate tensile strength, $\sigma_{ys}$ yielding strength, $E$ Young's module, $\nu$ Poisson's ratio.
		
		$\sigma_{uts}$ and $\sigma_{ys}$ are taken directly from the \texttt{ASTM B-221-05} \cite{ASTMB221} standard while other parameters came from T-slot producer's data-sheets  \cite{tslot-ds} \cite{parker-ds} \cite{8020-ds}.
	}	
	
	\rule{\linewidth}{2pt}
	
\end{table}

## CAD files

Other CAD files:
CAD/Assembly.iam
CAD/Horizontal track.iam
CAD/Inventor Component Part Files/01-Extrusion Profiles/01-40 series/10-016.ipt
CAD/Inventor Component Part Files/01-Extrusion Profiles/01-40 series/10-036.ipt
CAD/Inventor Component Part Files/01-Extrusion Profiles/01-40 series/10-040.ipt
CAD/Inventor Component Part Files/01-Extrusion Profiles/01-40 series/10-040B.ipt
CAD/Inventor Component Part Files/01-Extrusion Profiles/01-40 series/10-043.ipt
CAD/Inventor Component Part Files/01-Extrusion Profiles/01-40 series/10-044.ipt
CAD/Inventor Component Part Files/01-Extrusion Profiles/01-40 series/10-045.ipt
CAD/Inventor Component Part Files/01-Extrusion Profiles/01-40 series/10-080.ipt
CAD/Inventor Component Part Files/01-Extrusion Profiles/01-40 series/10-080B.ipt
CAD/Inventor Component Part Files/01-Extrusion Profiles/01-40 series/10-081.ipt
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

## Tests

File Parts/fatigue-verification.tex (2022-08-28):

\subsection{Fatigue verification}
	\paragraph{Most critical section} As already stated, the most critical section is subjected to a maximum stress of $\sigma_{max} \simeq 28.68MPa$. While functioning we expect that the turret performing the operation to the soil periodically moves along the track: having $\zeta$ varying over time determines that also the internal loads are fluctuating and this might arise fatigue failure of the machine.
	
	Given the need of a fatigue verification, acknowledged that the minimum bending load at $z^*$ is $M_{x,min} \simeq 14.05N\cdot m$ achieved for $\zeta = 0m$, it determines $\sigma_{min} \simeq 2.97MPa$; this further implies that the mean and amplitude stresses for fatigue verification are
	\[ \sigma_m \simeq 15.82 MPa \qquad \sigma_a \simeq 12.85MPa \]
	According to Soderberg criterion, the equivalent amplitude only stress component evaluates to
	\[ \sigma_{a,eq} = \frac{\sigma_{ys} \sigma_a}{\sigma_{ys} - \sigma_m} \simeq 13.76MPa  \] 
	In this case the load factor is $C_l=1$; given an equivalent diameter $d_{eq} = \sqrt{\frac 4\pi A} = 29mm$, the corresponding size factor is $C_d = 1.189d_{eq}^{-0.097} \simeq 0.86$; details concerning the surface finish of the T-slot beams are not enough to fully determine the surface coefficient $C_s$ that's assumed in this case to be $0.8$ as safety value. Considering an endurance limit of the 6061-T5 aluminium alloy of $\sigma_{lim} = 100MPa$ \cite{aluminium-endurance}, this means that the safety factor against fatigue failure is
	\[ \phi_\textrm{fatigue} = C_sC_dC_l\frac{\sigma_{lim}}{\sigma_{a,eq}} \simeq 4.98 \]

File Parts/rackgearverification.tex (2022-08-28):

\subsection{Design and static verification of rack and gear}
The verification continued with the parts responsible for actuating the machine, rack that is positioned on both tracks and gear attached on the motors' shaft.
We focused on two important aspects, interference and tooth root bending resistance.

\subsubsection*{Interference condition}
It's fundamental to check if this condition is fulfilled, because otherwise we could have a problem of undercut, when the tip of the rack cutter is moved beyond the base circle of the gear and the result is the weakening of the gear's teeth.

Interference condition is function of the minimum number of teeth of the pinion, in accordance with the following equation:
\begin{equation}
	\centering
	z_{min} = \frac{2}{sin^2\alpha},
\end{equation}
where $\alpha$ is the pressure angle, as we can see in figure \ref{fig:rack}.
\begin{SCfigure}[1][hbt]
	\centering
	
	\caption{standard rack and pressure angle $\alpha$.}
	\label{fig:rack}
\end{SCfigure}
In our case we designed the profile with a pressure $\alpha = 20^\circ$, thus we have:
\begin{equation*}
	z_{min} = 17
\end{equation*}

\subsubsection*{Gear design and verification}
	The gear attached to the motor's shaft is designed choosing as number of tooth $z=18$; assuming that the motors actuating the machines can generate a power $P=10W$ at $n = 50rpm$, the associated maximum generated torque is $T=1.9N\cdot m$. Choosing as module $m$ of the gear the value $2mm$, then the nominal diameter of the gear is $d = zm = 36mm$ and the maximum force that can be transmitted by the gear is
	\[ F = \frac T r = 2 \frac T d = 106N\]
	
	\paragraph{Tooth root fatigue resistance}	One of the most important problem in the usage of gears is the teeth fatigue resistance, due to the fact they're subjected to pulsating loads.  
	In our analysis we used the Lewis method that consider the tooth as a cantilever beam where shear and compressive normal stresses are neglected.
	
	According to such theory, the stress state acting on the tooth is
	\[ \sigma = \frac{F}{mb Y_l}\]
	where $b$ is the face width (figure \ref{fig:tooth}) and $Y_l$ is the Lewis factor taking into account for the shape of the tooth; such parameter depends on both the number of teeth $z$ and the pressure angle $\alpha$, and for the given data it evaluates to $Y_l = 0.308$.
	\begin{figure}[bt]
	\begin{subfigure}{.5\textwidth}
		\centering
		
		\caption{}
	\end{subfigure}%
	\begin{subfigure}{.5\textwidth}
		\centering
		
		\caption{}
	\end{subfigure}
	\caption{tooth details: section (a) and face width (b).}
	\label{fig:tooth}
	\end{figure}
	
	Given the ultimate tensile strength $\sigma_{uts} = 40MPa$ of plastic materials used in 3D printing machine and choosing a safety factor $\phi= 2$, reversing the Lewis equation gives us the minimum face width:
	\[ \sigma \leq \frac{\sigma_{uts}}{\phi} \qquad \Rightarrow \qquad b \geq \frac{F \phi}{Y_l m \sigma_{uts}} = 8.61mm \]
	thus a width $b = 10mm$ for the teeth has been chosen.
	
	\paragraph{Crushing verification} The gear is mounted to the motors shaft by means of a $3\times 3mm$ parallel key; the shaft is made of steel with high mechanical properties, while the gear, that can be 3D-printed, has lower stress capability, thus we need to verify the member at crushing.
	
	By the geometry of the gear reported in the annexes, the contact surface that is used to exchange the load is a rectangular surface of dimensions $b\times h = 10 mm \times 1.292mm$; given the augmented force $F = 447N$ (as the radius where the force is applied is reduced to $r = 4.25mm$) that has to be exchanged, the mean pressure at the contact surface is
	\[ p = \frac{F}{bh} = 34.62MPa \]
	Considering the allowable pressure $p_{all} = \sigma_{uts} = 40MPa$, then the safety factor against crushing of the gear is $\phi = 1.15$.
	
	\paragraph{Gear and rack design} With this calculation performed, using built-in tools provided by the software and simple sketches a custom design for both gear and rack has been developed in order to be 3D printed by the end user. Annex \ref{draw:gearrack} (page \pageref{draw:gearrack}) reports the technical drawing of both parts.
	
	Moreover exploiting the parametric capability of \texttt{AutoDesk Inventor} the rack length is fully modular and can be extended/reduced by a integer amount of teeth in order to match the 3D printer plate dimensions; in the drawing it has been considered a rack with $z = 60$ teeth giving an overall length $l = 377mm$.

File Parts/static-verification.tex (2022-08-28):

\subsection{Static verification}
	With all the geometrical values known, it has been possible to carry out a more detailed analysis. Considering a more complex model of the forces that takes into account also the distributed load due to the gravity and that the force $F$ is applied with an eccentricity $e=5cm$, it has been possible to parametrically define the hyperstatic variables as
	\[ X_1 \simeq \big( 0.63-0.16\zeta\big) N\cdot m \qquad X_2 \simeq -8.10 \ N\cdot m \] \[ X_3 \simeq \big( - 10.54 - 11.07\zeta + 55.53\zeta^2 - 6.17\zeta^3 \big) N\cdot m \]
	Evaluating the stress state on the 3 beams making up the structure for values of $\zeta \in [0,L]$, what we obtained is that the most critical section is in the elevated track for $\zeta^* = 1.65m$ at $z^* = 1.65m$ where the maximum bending value $M_x^* \simeq 135.64N\cdot m$ is achieved (as showed in figure \ref{fig:bending}). Knowing that $N^* = 0$ and neglecting the shear stress contribution due to both shear $V_y^* \simeq 111N$ and torque $M_z^* \simeq 1.89N\cdot m$, the stress state is
	\[ \sigma_{zz}(y) = \frac{M_x^*}{I_{xx,track}}y \qquad \Rightarrow \qquad \sigma_{zz,max} = \sigma_{zz}(2cm) \simeq 28.68 MPa   \]
	\begin{figure}[b]
		\centering 
		\caption{bending moment $M_x$ acting along the elevated track for 3 values o application point of the force; the first case is the minimum-stress condition, while the third one has the maximum bending peek value.} \label{fig:bending}
	\end{figure}
	This leads to a safety factor of $\phi = \sigma_{ys}/\sigma_{zz,max} \simeq 8.37$, meaning that the structure is statically verified. This value is more then twice than the one achieved in the preliminary design phase but is due to the fact that in this case the full analytical solution of the hyperstatic problem has been considered, having determined all geometrical properties of the sections. As a reminder:
	\begin{itemize}
		\item due to the lack of analytical formulas for such complex geometry section, shear components due to torque and shears are neglected and could have influenced the mechanical system;
		\item we did not consider external forces acting that might act on the global $x$ axis due to the actuation of the machine or accidental load applied by the end user: this can lead to an increase in bending and torques that might make the system fail; a high safety factor ensures us the reliability of the system also in such conditions.
	\end{itemize}
	
	\paragraph{Stiffness verification} At this point we can also perform a stiffness verification to understand the behaviour of the mechanical system, in particular the displacement with respect to the nominal position of the turret used to perform the operation to the soil. Given the high safety factor and observing that axial load are not that relevant, we considered the two vertical supports as rigid bodies. At this point the radial displacement $v(t)$ from the nominal configuration is related only to the bending action by the law
	\[ v(z) = - \frac{M_x}{2EI_{xx}}z^2 \]
	
	In our study case we have that $M_x$ depends on the point of application of the external force $F$ that's function of $\zeta$, the position of the turret itself (so our point of interest). This allows us to plot the vertical displacement of the turret as function of the position of the turret as in figure \ref{fig:displacement}. 
	\begin{figure}[tb]
		\centering 
		\caption{vertical displacement of the turret from the nominal configuration.} \label{fig:displacement}
	\end{figure}

	The reported graph contradicts a requirement of our customer as the maximum displacements is bigger than $4cm$, exceeding the least target displacement value of $1cm$. This suggest that the chosen profile \texttt{10-040} is not able to withstand all the requirements. In order to solve this problem two paths can be followed:
	\begin{itemize}
		\item use the mathematical model of the machine in the control system to compensate for such displacement;
		\item use a different profile with better response at deflection. Looking at the IPS catalogue, a suitable alternative is the \texttt{10-080} profile whose section is reported in figure \ref{fig:10-080}. Such beam is characterized by a moment of inertia $I_{xx} = 71.56cm^4$: neglecting the difference in weight contribution of the bar (whose density is increased to $\rho = 3.18kg/m$),  the maximum displacement is reduced to less then $6mm$, fully satisfying the customers requirement.
	\end{itemize}
	\begin{SCfigure}[3][bht]
		\centering
		
		\caption{section of the \texttt{10-080} T-slot profile by Parker IPS\cite{parker-ds}.}
		\label{fig:10-080}
	\end{SCfigure}
	
	In the following (and also in the final CAD) the solution based on the \texttt{10-040} profile is reported, however, due to the high \textit{modularity} provided by the T-slot profiles, assembling the machine with the \texttt{10-080} component will be practically the same.

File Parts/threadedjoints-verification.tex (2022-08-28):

\subsection{Threaded joints verification}
\subsubsection*{Preliminary design}
Given the customer's requirements, the threaded fasteners used for the threaded joints in the whole robot are chosen to be standard screws with diameter of $8mm$, compatible with the $40mm$ T-slot profiles.

Considering the threaded joints present on the robot, the maximum thickness of the members is given by the sum between the beam cross section's width, $40 mm$, and the machined gussets thickness, $8 mm$. Given that two screws must fit, as in section $A$, the length of the screws is chosen to be equal to $18 mm$, according to \texttt{UNI ISO 888}; table \ref{tab:boltchoise} reports the main properties of the chosen bolt used for the verification of the connections.

\begin{table}[bth]
	\rule{\linewidth}{2pt}
	\caption{selected bolt chosen from the Parker IPS catalogue \cite{parker-ds} and related main properties.}
	\label{tab:boltchoise}
	\rule{\linewidth}{1pt} 
	\begin{center}
	\begin{tabular}{r c c}
		Parameter & symbol & value \\ \hline
		diameter & $d$ & $8mm$ \\
		head diameter & $d_0$ & $14mm$ \\
		length & $l$ & $18mm$ \\
		cross-section & $A_b$ & $16\pi mm^2$ \\
		tensile cross-section & $A_{bt}$ & $36.6mm^2$ \\
		ultimate tensile strength & $\sigma_{uts}$ & $505MPa$ \\
		product code & \multicolumn{2}{c}{\texttt{24-118-8}}
	\end{tabular}
	\end{center}
	\rule{\linewidth}{2pt}
\end{table}

With reference to figure \ref{fig:freebodydiagramframe}, threaded joints are present in sections $A$, $B$, $C$ and $D$. The verifications are carried out with respect to the most critical sections which, according to the load analysis performed previously, are identified as section $A$ and $D$. Moreover, since the load distribution depends on the position of the point of application of the external load, the most critical condition corresponds to the one in which the load is applied in $\zeta = 1$ for section $A$ and $\zeta = 3$ for section $D$.\\
\subsubsection*{Section A}
The loads applied on section $A$ are the following:\\
\begin{itemize}
	\item axial load $N_{A} = -251.13 N$;
	\item bending moment $M_{xA} = -12.65 N\cdot m$; 
	\item bending moment $M_{yA} = 1.89 N\cdot m$; 
	\item torque $M_{zA} = -0.59 N\cdot m$.
\end{itemize}
In correspondence of section $A$, there are two machined gussets chosen from the Parker IPS catalogue \cite{parker-ds}, reported in figure \ref{fig:gusset}.
Given the geometry of the component, the threaded joints are positioned on the vertical $z$ and horizontal $x$ global axis.  For this reason, two separated analysis are performed. 
\begin{SCfigure}[1.5][bht]
	\centering
	
	\caption{machined gusset, code \texttt{10-102}, from the IPS catalogue \cite{parker-ds}. In the drawing: $A = 77mm$, $B=77mm$, $C = 34mm$, $D= 20mm$, $E=40mm$, $F=8mm$, $G=9mm$.}
	\label{fig:gusset}
\end{SCfigure}

\paragraph{Threaded joints along the $x$ axis} The loads acting on section A the $x$ axis are represented in figure \ref{fig:sectionxA}.\\
\begin{figure}[h!]
    \centering
    \begin{subfigure}{0.32\linewidth}
    	\centering  
	\end{subfigure}\\
	\begin{subfigure}{0.32\linewidth}
		\centering 
	\end{subfigure}\\
	\begin{subfigure}{0.32\linewidth}
		\centering  
	\end{subfigure}    
    \caption{Loads on section A, along the $x$ axis.}
    \label{fig:sectionxA}
\end{figure}\\
The sliding actions are given by the torque $M_{zA}$, which produces a shear force on every screw equal to:\\
\begin{equation*}
    V_{i} = \frac{M_{z1}r_{i}}{\sum\limits_{i=1}^{n_{{b}}} r^2_{i}}
\end{equation*}
where $r_{i}$ are the distances of every screw from the center of the section, and are equal to $r_{1} = 40 mm$, $r_{2} = 80 mm$. 
The shear force is calculated for the most critical screws, distant $r_{2}$ , and it is equal to:\\
\begin{equation*}
    V_{2} = \frac{M_{zA}r_{2}}{2r^2_{1}+2r^2_{2}} = - 2.97 N
\end{equation*}
The shear and punching resistance verifications can be performed as follow:
\begin{itemize}
    \item shear resistance verification:
    \begin{equation*}
        |V_{2}| < \frac{\sigma_{uts}A_{b}}{\phi}
    \end{equation*}
    where $\sigma_{uts}$ corresponds to the screw's ultimate tensile strength, $A_{b}$ to the bolt cross-section and $\phi$ is the safety factor which, according to Eurocode3, is equal to $\frac{1.25}{0.58}$.
    As a consequence, it follows that:
    \begin{equation*}
       \sigma_{uts} > \frac{|V_{2}|\phi}{A_{b}} = 0.13 MPa
    \end{equation*}\\
    \item crushing resistance verification:
    \begin{equation*}
        |V_{2}| < \frac{\sigma_{uts,m}dt}{\phi}
    \end{equation*}
    where $\sigma_{uts,m}$ corresponds to the member's ultimate tensile strength, $d$ to the bolt diameter and $\phi$ is the safety factor which, according to Eurocode3, is equal to 0.5. Finally, $t$ corresponds to the member's thickness, which can be calculated as the sum of the machined gusset thickness, $F = 8 mm$, and the base's thickness, equal to $16 mm$:
     \begin{equation*}
       \sigma_{uts,m} > \frac{|V_{2}|\phi}{dt} = 7.73 \cdot 10^{-3} MPa
    \end{equation*}
\end{itemize}
Separating actions are given by the axial load and the bending moments.\\
Assuming that the members are rigid it is possible to calculate the effects of the separating actions in both $xz$ and $yz$ planes.\\
The load caused by the separating action, acting on each bolt can be calculated as:\\
\begin{equation*}
    N_{i} = \frac{M_{b}h_{i}}{\sum\limits_{i=1}^{n_{b}} h^2_{i}} + \frac{N}{n_{b}}
\end{equation*}
Considering the $xz$ plane and assuming that the pivot is placed on the edge of the section, the constant $     h_{i}$ will be equal to:
\begin{equation*}
   \begin{cases}
    h_{1} = 17 mm\\
    h_{2} = 57 mm\\
    h_{3} = 137 mm\\
    h_{4} = 177 mm\\
    \end{cases} 
\end{equation*}
The normal load is calculated for the most critical screw as follow:\\
\begin{equation*}
    N_{xz} = \frac{M_{yA}h_{4}}{h_{1}^{2}+h_{2}^{2}+h_{3}^{2}+h_{4}^{2}} + \frac{N_{1}}{n_{b}} = - 56.53 N
\end{equation*}
Since the axial load acting on every bolt is negative, i.e. the bolt are subjected to compression, there are no issues relative to tension and punching resistance. As a consequence, it is not necessary to perform those verifications. 

Considering the $yz$ plane and assuming that the pivot is placed on the edge of the section, the constants $h_{i}$ will be all equal to $h = \frac{C}{2} = 17 mm$.
The normal load is equal to:
\begin{equation*}
    N_{yz} = \frac{M_{xA}h}{4h^{2}} + \frac{N_{1}}{n_{b}} = 123.18 N
\end{equation*}
The tension resistance and punching verification can be performed as follow:
\begin{itemize}
    \item tension resistance verification:
    \begin{equation*}
        N_{yz} < \frac{\sigma_{uts}A_{bt}}{\phi}
    \end{equation*}
    Where $\sigma_{uts}$ corresponds to the screw's ultimate tensile strength, $A_{bt}$ to the bolt tensile cross-section and $\phi$ is the safety factor which, according to Eurocode3, is equal to $\frac{1.25}{0.9}$. As a consequence, it follows that:
    \begin{equation*}
       \sigma_{uts} > \frac{N_{yz}\phi}{A_{bt}} = 4.67 MPa
    \end{equation*}
    \item punching resistance verification:
    \begin{equation*}
        N_{yz} < \frac{\pi d_{0} t \sigma_{uts,m}}{\phi}
    \end{equation*}
    Where $\sigma_{uts,m}$ corresponds to the member's ultimate tensile strength, $d_{0}$ the bolt head diameter and $\phi$ is the safety factor which, according to Eurocode3, is equal to $\frac{1.25}{0.6}$. Finally, $t$ corresponds to the member's thickness, which can be calculated as the sum of the gusset's thickness, $F = 8 mm$, and the base's thickness, equal to $16 mm$:
     \begin{equation*}
       \sigma_{uts,m} > \frac{N_{yz}\phi}{\pi d_{0}t} = 0.24 MPa
    \end{equation*}
\end{itemize}

\paragraph{Threaded joints along the $z$ axis}  The loads acting on section A the $z$ axis are represented in figure \ref{fig:sectionxA}.\\
\begin{figure}[h!]
    \centering
	
    \caption{Loads on section A, along the $z$ axis.}
    \label{fig:sectionzA}
\end{figure}
In this case the sliding actions are given by $M_{xA}$ and $N_A$ which produce a shear force on every screw equal to:
\begin{equation*}
    V_{i} = \frac{M_{xA}r_{i}}{\sum\limits_{i=1}^{n_{{b}}} r^2_{i}} + \frac{N_{A}}{n_{b}}
\end{equation*}
where $r_{i}$ are the distances of every screw from the center of the section, and are equal to $r = 21.5 mm$.
\begin{equation*}
    V = \frac{M_{xA}r}{2r^2} +  \frac{N_{A}}{2} = 140.41 N
\end{equation*}
\begin{itemize}
    \item shear resistance verification:
    \begin{equation*}
       \sigma_{uts} > \frac{V\phi}{A_{b}} = 6.20 MPa
    \end{equation*}
    \item crushing resistance verification:
     \begin{equation*}
       \sigma_{uts,m} > \frac{V\phi}{dt} = 0.18 MPa
    \end{equation*}
\end{itemize}

The separating actions, $M_{yA}$ and $M_{zA}$ generates normal load on each and the effects are studies as previously for yz and xy plane.
\begin{equation*}
    N_{i} = \frac{M_{b}h_{i}}{\sum\limits_{i=1}^{n_{b}} h^2_{i}} + \frac{N}{n_{b}}
\end{equation*}
Considering the $yz$ plane and assuming that the pivot is placed on the edge of the section, the constants $h_{i}$ will be equal to $h_1 = D = 20 mm$ and $h_2 = D + E = 60 mm$.
The normal load is evaluated for the most critical screw and is equal to:
\begin{equation*}
    N_{xz} = \frac{M_{yA}h_{2}}{h_{1}^{2}+h_{1}^{2}} = 28.40 N
\end{equation*}
\begin{itemize}
    \item tension resistance verification:
     \begin{equation*}
       \sigma_{uts} > \frac{N_{yz}\phi}{A_{bt}} = 1.08 MPa
    \end{equation*}
    \item punching resistance verification:
     \begin{equation*}
       \sigma_{uts,m} > \frac{N_{yz}\phi}{\pi d_{0}t} = 27.46 \cdot 10^{-3} MPa
    \end{equation*}
\end{itemize}
Finally, considering the xy plane, assuming that the pivot is placed on the edge of the section, the constants $h_{i}$ will be all equal to $h = \frac{C}{2} = 17 mm$ the normal load is equal to: \\
\begin{equation*}
    N_{xy} = \frac{M_{zA}h}{2h^{2}} = 17.47 N
\end{equation*}
\begin{itemize}
    \item tension resistance verification:
     \begin{equation*}
       \sigma_{uts} > \frac{N_{xy}\phi}{A_{bt}} = 0.66 MPa.
    \end{equation*}
    \item punching resistance verification:
     \begin{equation*}
       \sigma_{uts,m} > \frac{N_{xy}\phi}{\pi d_{0}t} = 16.89 \cdot 10^{-3} MPa.
    \end{equation*}
\end{itemize}

\subsubsection*{Section D}
The loads applied on section $D$ are the following:
\begin{itemize}
	\item axial load $N_{D} = 233.01 N$;
	\item bending moment $M_{xD} = 0 N\cdot m$; 
	\item bending moment $M_{yD} = 8.11 N\cdot m$; 
	\item torque $M_{zD} = -0.59 N\cdot m$.
\end{itemize}
In correspondence of section $D$, there is a pivot joint chosen from the Parker IPS catalogue \cite{parker-ds}, reported in figure \ref{fig:pivot}.
\begin{figure}[h!]
    \centering
    \begin{subfigure}{0.32\linewidth}
    	\centering 
    \end{subfigure}
	\begin{subfigure}{0.32\linewidth}
		\centering  
	\end{subfigure}
	\begin{subfigure}{0.32\linewidth}
		\centering 
	\end{subfigure}    
    \caption{pivot joint, code \texttt{23-010}, from the IPS catalogue \cite{parker-ds}. In the drawing: $A = 40mm$, $B=30mm$, $C=9mm$, $D=40mm$, $E=8.5mm$, $F=60mm$.}
    \label{fig:pivot}
\end{figure}\\
The loads action on section D are reported in figure \ref{fig:loadsD}
\begin{SCfigure}[1.5][h!]
	\centering
	
	\caption{loads acting on section D}
	\label{fig:loadsD}
\end{SCfigure}

In this case, the sliding actions are given by the torque $M_{zD}$,  figure \ref{fig:pivot}\textit{(b)}. However, since there is a single screw positioned in the center of the section, they do not cause any shear on the screw.

Separating actions are given by the axial load and the bending moments. Assuming that the members are rigid it is possible to calculate the effects of the separating actions in both $xz$ and $yz$ planes. The load caused by the separating action, acting on the screw can be calculated as:
\begin{equation*}
    N_{i} = \frac{M_{b}h_{i}}{\sum\limits_{i=1}^{n_{b}} h^2_{i}} + \frac{N}{n_{b}}
\end{equation*}\\
where $h_{i}$ is the distance of the $i$-th bolt from the pivot point.
\begin{equation*}
    N_{xz} = \frac{M_{yD}}{h} + N_{D} = 638.33 N
\end{equation*}

Considering the $xz$ plane and assuming the pivot on the edge of the section, $h$ is equal to $\frac{A}{2} = 20 mm$. The tension resistance and punching verification can be performed as follow:
\begin{itemize}
    \item tension resistance verification:
    \begin{equation*}
        N_{xz} < \frac{\sigma_{uts}A_{bt}}{\phi}
    \end{equation*}
    Where $\sigma_{uts}$ corresponds to the screw's ultimate tensile strength, $A_{bt}$ to the bolt tensile cross-section and $\phi$ is the safety factor which, according to Eurocode3, is equal to $\frac{1.25}{0.9}$. As a consequence, it follows that:
    \begin{equation*}
       \sigma_{uts} > \frac{N_{xz}\phi}{A_{bt}} = 24.22 MPa
    \end{equation*}
    \item punching resistance verification:
    \begin{equation*}
        N_{xz} < \frac{\pi d_{0} t \sigma_{uts,m}}{\phi}
    \end{equation*}
    Where $\sigma_{uts,m}$ corresponds to the member's ultimate tensile strength, $d_{0}$ the bolt head diameter and $\phi$ is the safety factor which, according to Eurocode3, is equal to $\frac{1.25}{0.6}$. Finally, $t$ corresponds to the member's thickness, which can be calculated as the sum of the pivot joint thickness, $C = 9 mm$, and the member's cross section, equal to $40 mm$:
     \begin{equation*}
       \sigma_{uts,m} > \frac{N_{xz}\phi}{\pi d_{0}t} = 0.62 MPa
    \end{equation*}
\end{itemize}
Considering instead the $xz$ plane we have:\\
\begin{equation*}
    N_{yz} = \frac{M_{xD}}{h} + N_{D} = 233.01 N
\end{equation*}
thus:
\begin{itemize}
    \item tension resistance verification:
    \begin{equation*}
        N_{yz} < \frac{\sigma_{uts}A_{bt}}{\phi} \qquad \Rightarrow \sigma_{uts} > \frac{N_{yz}\phi}{A_{bt}} = 8.84 MPa
    \end{equation*}
    \item punching resistance verification\\
    \begin{equation*}
        N_{yz} < \frac{\pi d_{0} t \sigma_{uts,m}}{\phi} \qquad \Rightarrow \qquad   \sigma_{uts,m} > \frac{N_{yz}\phi}{\pi d_{0}t} = 0.23 MPa
    \end{equation*}
\end{itemize}
In conclusion, the bolt ultimate strength must be greater than $24.22 MPa$, a value that allows to choose any bolt property class. In order to minimize the costs, property 4.6 is chosen.

Moreover, the verifications for crushing and punching provide the minimum member ultimate strength, $\sigma_{uts,m} > 0.23 MPa$, value much smaller than the chosen member's UTS.

Note that for the verifications of the separating actions the rigid member approach was used, which is usually more conservative than the others. However, since the values obtained are far distant from the one of the selected materials, there is no need of a more precise verification.

As for most applications, the preload used to tighten the bolts is chosen to be 80$\%$ of the yield strength. At this point, the stiffness joint verification should be performed. However, due to the low external loads acting on the bolts, no issue will arise and there is no need to carry out this analysis.

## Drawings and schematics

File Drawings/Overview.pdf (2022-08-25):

B C

C

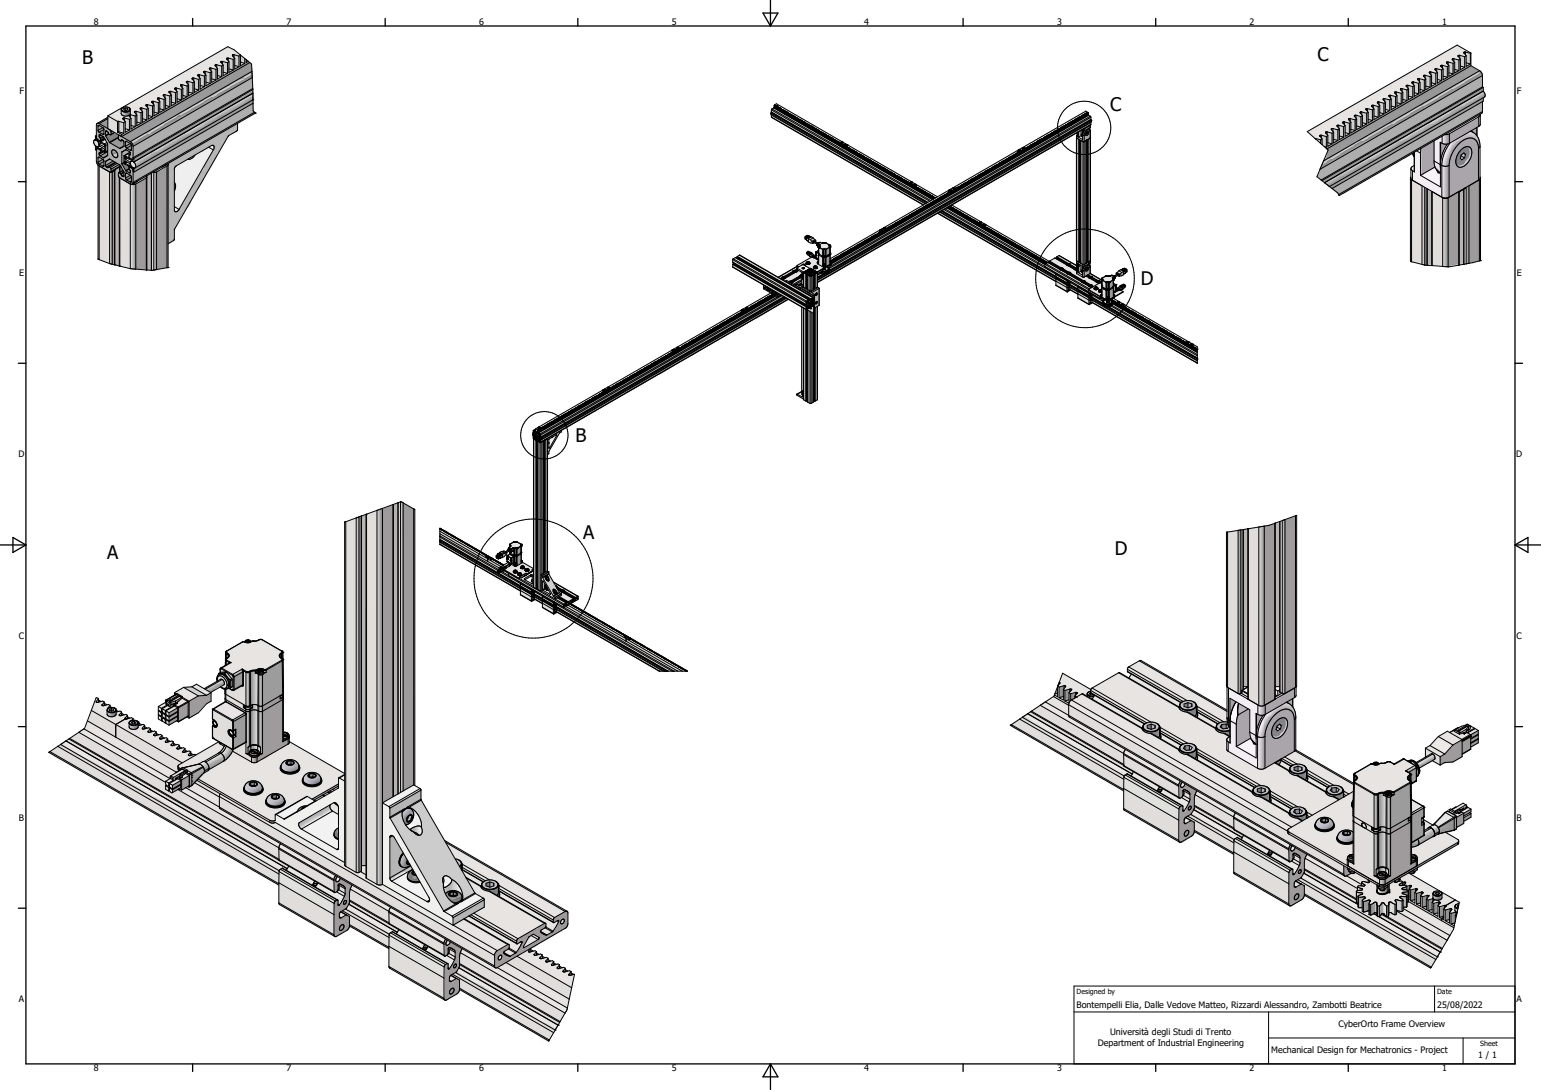
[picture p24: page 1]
Bontempelli Elia, Dalle Vedove Matteo, Rizzardi Alessandro, Zambotti Beatrice; Designed by; Date; Sheet

CyberOrto Frame Overview

Università degli Studi di Trento
Department of Industrial Engineering

Mechanical Design for Mechatronics - Project

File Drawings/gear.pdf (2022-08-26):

# A-A ( 2 : 1 ) A

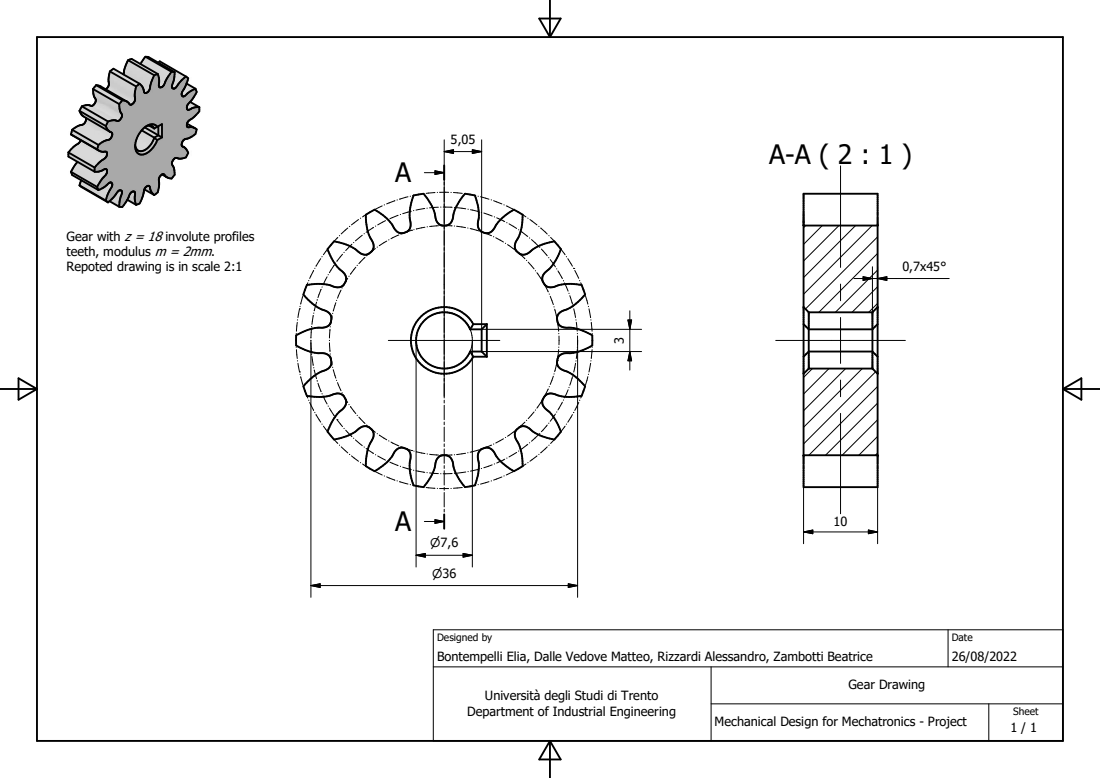
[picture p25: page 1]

Gear with z = 18 involute profiles
teeth, modulus m = 2mm.
Repoted drawing is in scale 2:1

Designed by Bontempelli Elia, Dalle Vedove Matteo, Rizzardi Alessandro, Zambotti Beatrice | Date 26/08/2022

Università degli Studi di Trento Department of Industrial Engineering | Gear Drawing

Mechanical Design for Mechatronics - Project | Sheet 1 / 1

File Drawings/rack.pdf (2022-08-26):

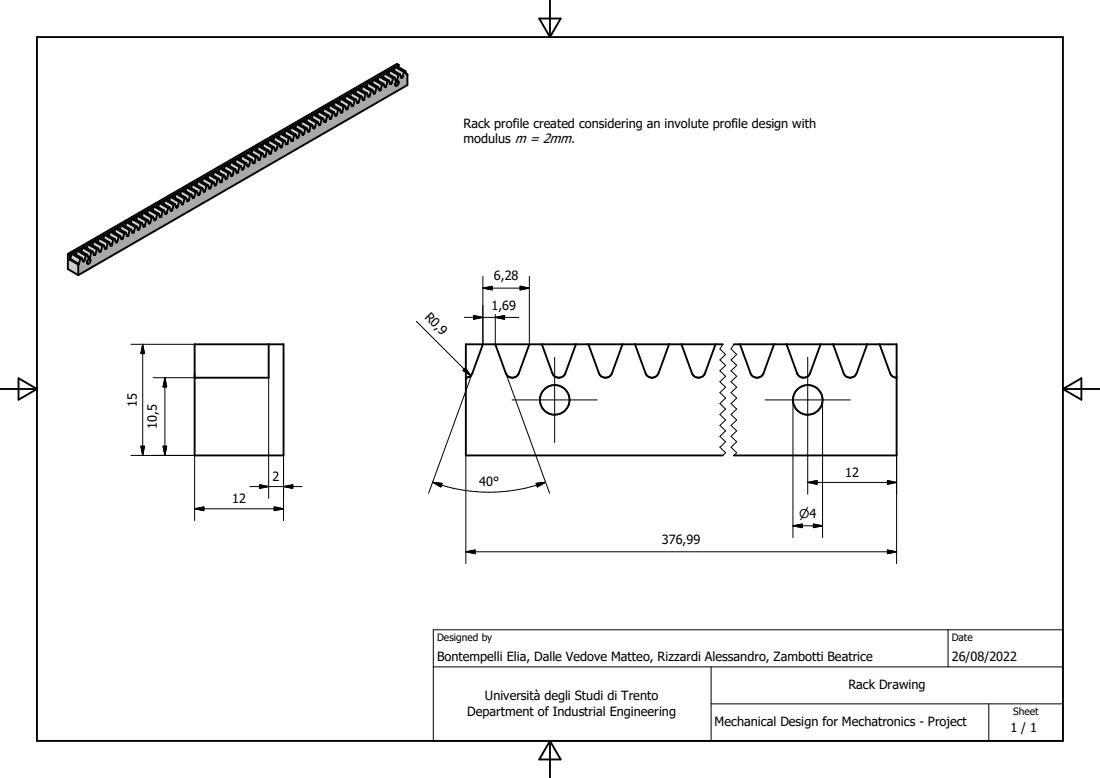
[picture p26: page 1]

Rack profile created considering an involute profile design with
modulus m = 2mm.

Designed by Bontempelli Elia, Dalle Vedove Matteo, Rizzardi Alessandro, Zambotti Beatrice | Date 26/08/2022

Università degli Studi di Trento Department of Industrial Engineering | Rack Drawing

Mechanical Design for Mechatronics - Project | Sheet 1 / 1

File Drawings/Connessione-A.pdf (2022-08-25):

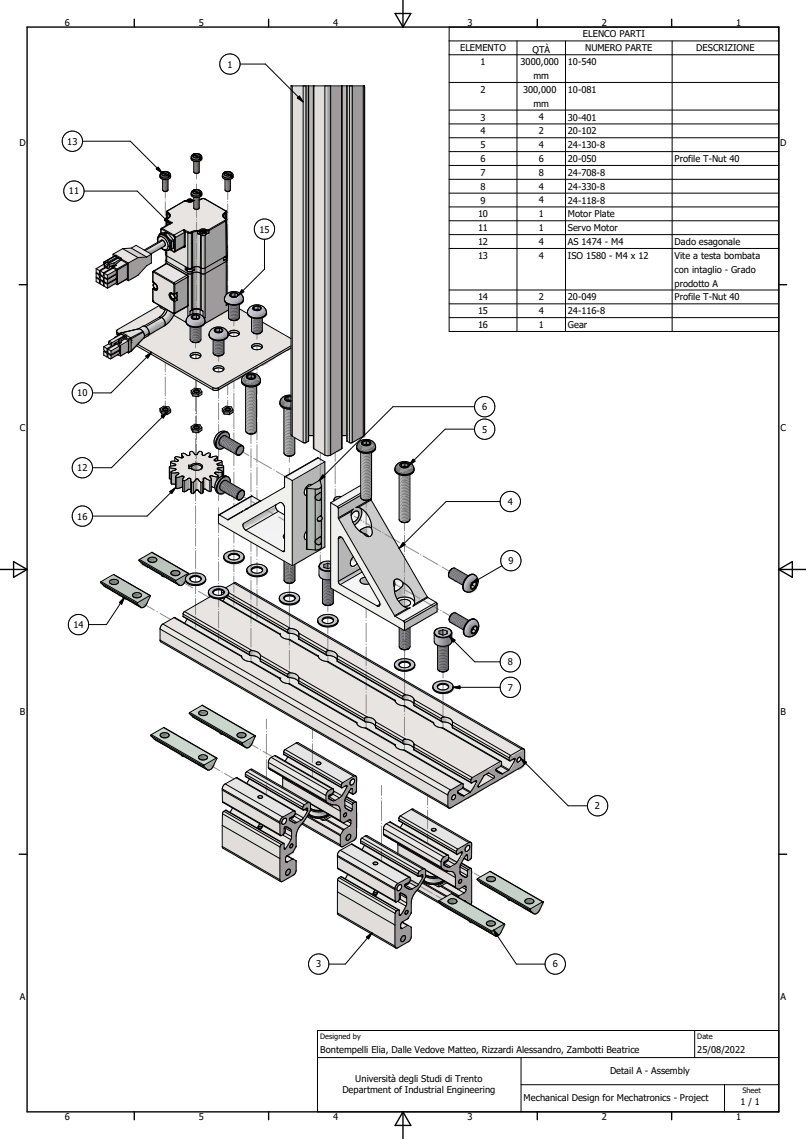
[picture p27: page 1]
ELENCO PARTI; ELEMENTO; QTÀ; NUMERO PARTE; DESCRIZIONE; Profile T-Nut 40; Motor Plate; Servo Motor; Dado esagonale; ISO 1580 - M4 x 12; Gear; Detail A - Assembly; Bontempelli Elia, Dalle Vedove Matteo, Rizzardi Alessandro, Zambotti Beatrice; Designed by; Date; Sheet

Vite a testa bombata
con intaglio - Grado
prodotto A

Università degli Studi di Trento
Department of Industrial Engineering

Mechanical Design for Mechatronics - Project

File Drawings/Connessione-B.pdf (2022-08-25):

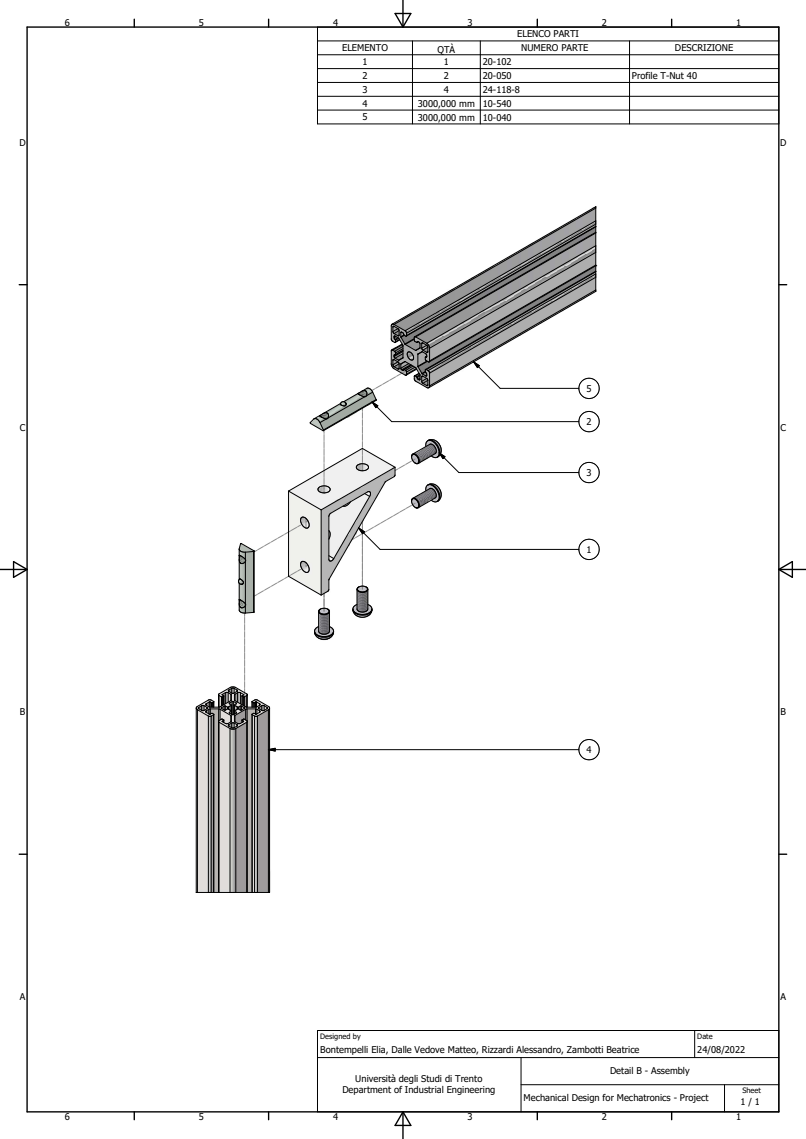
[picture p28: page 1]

ELENCO PARTI

ELEMENTO | QTÀ | NUMERO PARTE | DESCRIZIONE
1 | 1 | 20-102
2 | 2 | 20-050 | Profile T-Nut 40
3 | 4 | 24-118-8
4 | 3000,000 mm | 10-540
5 | 3000,000 mm | 10-040

Designed by Bontempelli Elia, Dalle Vedove Matteo, Rizzardi Alessandro, Zambotti Beatrice | Date 24/08/2022

Università degli Studi di Trento Department of Industrial Engineering | Detail B - Assembly

Mechanical Design for Mechatronics - Project | Sheet 1 / 1

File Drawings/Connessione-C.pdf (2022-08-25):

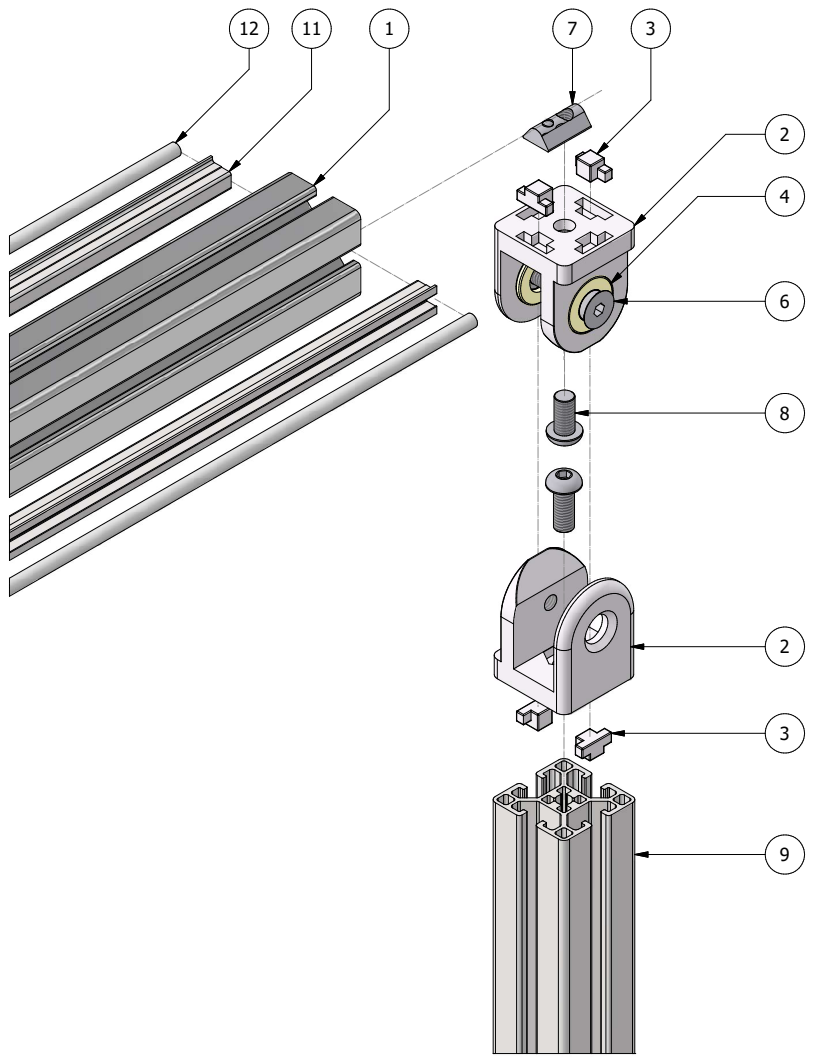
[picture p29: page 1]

ELENCO PARTI

ELEMENTO | QTÀ | NUMERO PARTE | DESCRIZIONE
1 | 3000,000 mm | 10-040
2 | 2 | 23-010Z1
3 | 4 | 23-010Z2
4 | 2 | 23-010Z3
5 | 2 | 23-010Z4
6 | 2 | 24-212-8
7 | 1 | 20-058
8 | 1 | 24-116-8
9 | 100,000 mm | 10-540
10 | 1 | 24-120-8
11 | 200,000 mm | 13-106
12 | 200,000 mm | 13-513

Designed by Bontempelli Elia, Dalle Vedove Matteo, Rizzardi Alessandro, Zambotti Beatrice | Date 24/08/2022

Università degli Studi di Trento Department of Industrial Engineering | Detail C - Assembly

Mechanical Design for Mechatronics - Project | Sheet 1 / 1

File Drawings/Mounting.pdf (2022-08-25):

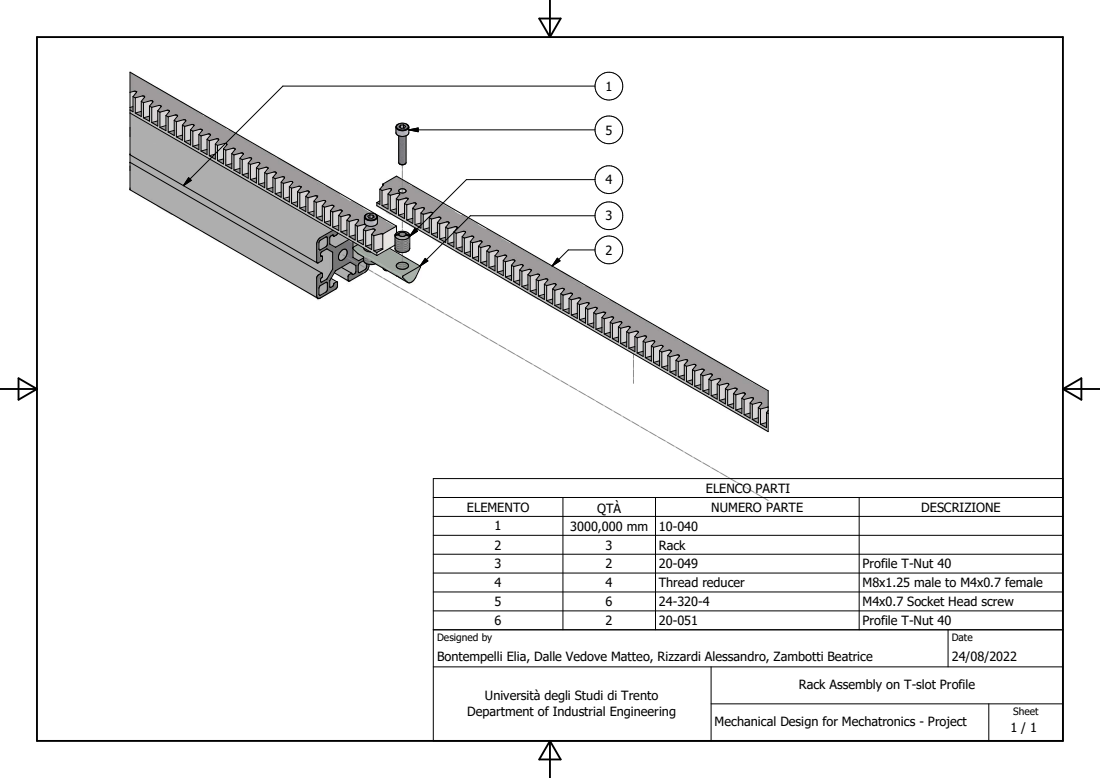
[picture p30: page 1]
ELENCO PARTI

ELEMENTO | QTÀ | NUMERO PARTE | DESCRIZIONE
1 | 3000,000 mm | 10-040
2 | 3 | Rack
3 | 2 | 20-049 | Profile T-Nut 40
4 | 4 | Thread reducer | M8x1.25 male to M4x0.7 female
5 | 6 | 24-320-4 | M4x0.7 Socket Head screw
6 | 2 | 20-051 | Profile T-Nut 40

Designed by Bontempelli Elia, Dalle Vedove Matteo, Rizzardi Alessandro, Zambotti Beatrice | Date 24/08/2022

Università degli Studi di Trento Department of Industrial Engineering | Rack Assembly on T-slot Profile

Mechanical Design for Mechatronics - Project | Sheet 1 / 1

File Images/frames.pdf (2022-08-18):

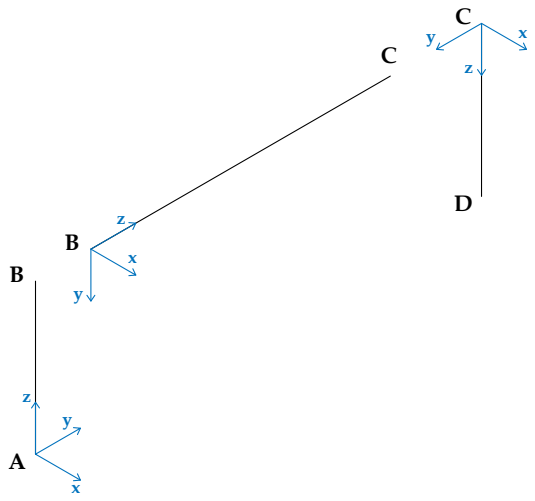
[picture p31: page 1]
DCz x z

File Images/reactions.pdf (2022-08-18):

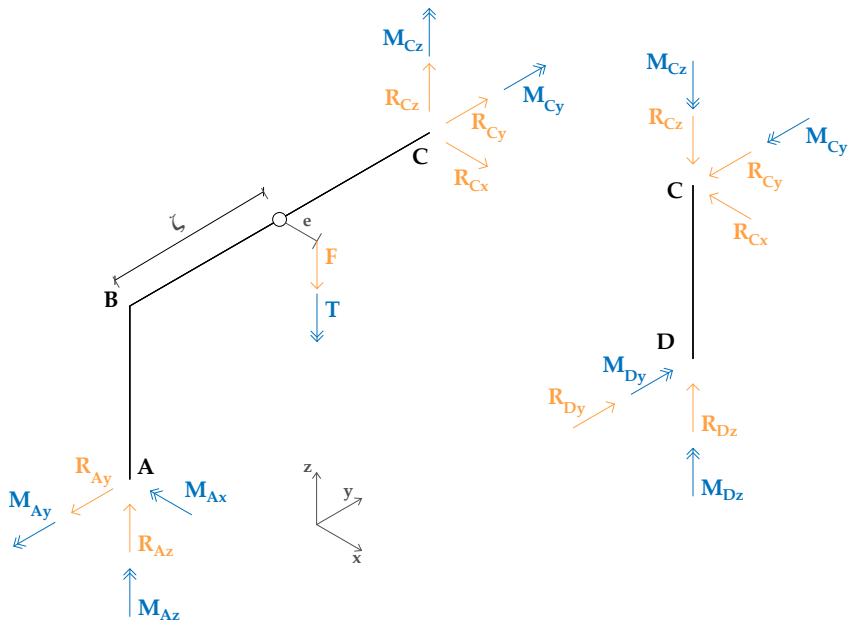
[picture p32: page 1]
CD ζ RAz RAy MAy; MAz MAx; RCz MCz; RCy MCy RCx; RCy; MCy RCx RDz MDz RDy MDy

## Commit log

2021-10-28 Product design specification impostata
    Introdotto CyberOrto e MindsHub
    Funzioni della macchina
    Requirements
    Alcuni carichi e condizioni di lavoro
2021-10-28 Created Readme
    Piccolo crash course di Latex
2021-12-02 Material selection added
2021-12-22 Inventor First Upload
    [10-016.0018.ipt, 10-016.ipt, 10-036.ipt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]
2021-12-23 Horizontal support
    First assembly of the horizontal support
    [10-081.ipt, 10-240.0015.ipt, 10-240.ipt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]
2021-12-23 Horizontal track
    Assembly file
    [Horizontal track.iam]
2022-08-17 Removed CAD files
    [10-016.0018.ipt, 10-016.ipt, 10-036.ipt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]
2022-08-19 Threaded Joints
2022-08-19 rack gear verification
2022-08-19 update rack gear
2022-08-20 Bolts continued
2022-08-20 gear design
2022-08-20 Added gear crushing verification
2022-08-22 Gear and rack technical drawing
2022-08-25 Added details drawing and BOM update
